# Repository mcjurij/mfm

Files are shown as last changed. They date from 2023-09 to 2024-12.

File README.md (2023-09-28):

# mfm
Mains Frequency Measurement

English: [English version](README_en.md)

Ziel des Projektes ist eine möglichst genaue Messung der Netzfrequenz.

* Dies ist ein reines Spassprojekt,
* ich verdiene mein Geld weder mit Hardwareentwicklung noch mit Embeddedprogrammierung,
* einige meiner Designentscheidungen sind daher u.U. suboptimal. :-)

Mit "Linux PC" ist in meinem Fall ein Fedora (z.Z. Fedora 37) gemeint. Die genutzte Distro spielt aber keine Rolle.

## Über die zwei grundsätzlichen Arten Frequenzen zu messen

1. Man kann ein Gate für eine exakte Zeit (zB genau 1 Sekunde) öffenen und dann zählen wieviele Impulse, erkannt an einer Triggerschwelle, in dieser Zeit erkannt wurden. Dies ist das "klassische" Frequency Counting. Bei hohen Frequenzen funktioniert das ausgezeichnet.

2. Man kann warten bis der Trigger erreicht ist, lässt dann immer wieder neu triggern und bestimmt den Zeitunterschied zwischen den beiden Triggerevents. Um eine hohe Genauigkeit zu erreichen wird dies über eine längere Zeit gemacht, d.h. über mehrer Perioden des Eingangssignals.

Für eine genaue Bestimmung einer Frequenz im Bereich von 50 Hz, also einer sehr niedrigen Frequenz, mit einer Genauigkeit von mindestens +/ 1mHz eher besser, ist Verfahren Nr 2 offensichtlich das einzig geeignete. Bei Verfahren Nr 1 müsste man sehr lange Messen um genug Impulse gesehen zu haben.

Verfahren 2 hat allerdings einen Nachteil. Will man immer die selbe Anzahl an Perioden messen, was hier gemacht wird denn es werden immer 50 Perioden abgemessen, dann ist die MessDAUER abhängig vom MessWERT. Bei einer Frequenz über 50 Hz ist die Messung kürzer als 1 Sekunde. Bei einer Messung unter 50 Hz, länger. Dies zu erwähnen ist wichtig, denn viele mathematische Verfahren gehen von äquidistanten Werten aus. Und auch die Berechnung der Netzzeit benötigt Messwerte im Abstand von 1 Sekunde.

## Über Quarze

Es gibt verschiedene Arten eine Frequenz von zB exakt 10 Mhz zu erzeugen. Standardquarze, temperaturkompensierte Quarze und Quarzöfen (Oven Controlled Crystal Oscillator, OCXO) sind die gängisten Methoden, wobei jeweils eine Balance zwischen Kosten/Aufwand und Anforderung der Anwendung gefunden werden muss. Ein Standardquarz war für meinen Geschmack zu ungenau. Standardquarze sind recht temperaturabhängig. Diese Temperaturabhängigkeit konnte ich in meinen Experimenten deutlich sehen. Eine Genauigkeit von +/- 1 mHz war so nicht zu erreichen, IMO.

Ein temperaturkompensierter Quarz (Temperature Compensated Crystal Oscillator, TCXO) korrigiert den Fehler nach Messung der Temperatur des Quarzes. Das Verfahren ist i.A. sehr viel genauer als ein Standardquarz. Diese sind aber schwer zu bekommen.

Ein Quarzofen hält die Temperatur des Quarzes auf einem konstantem Level. Die Genauigkeit der Frequenz hängt hier im wesentlichem nur noch von der Genauigkeit der Temperaturmessung und des Regelkreises ab. Man bekommt zB den von mir verwendeten Quarzofen für unter 20 Eur auf EBay aus China, inkl. Versand. Und für einen OCXO ist das sehr sehr günstig.  Und ist der Grund warum ich mir die Option TCXO nicht weiter angeschaut habe.

[Beschreibung Hardware](hardware.md)

[Beschreibung Software](software.md)

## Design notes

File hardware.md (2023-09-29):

## Hardware

Das mfm Projekt besteht aus 4 hardware Komponenten. Wovon eine doppelt vorhanden ist.

* Ein GPS disciplined oscillator (GPSDO oder auch GPSDXO) mit 1PPS Ausgang

* Ein oven-controlled crystal oscillator (OCXO) mit 10 Mhz TTL Ausgang (Clock), versorgt über Steckernetzteil.

* Eine "Distributor" genannte Platine zum verdoppeln der 10Mhz Clock und 1PPS Signale, versorgt über Netzanschluss. Schaltplan: Distributor.

* Zwei Platinen mit der Schaltung zur Netzfrequenzmessung. Schaltpläne: Counter ATmega328p v1 & v2. Beide sind fast identisch und haben 3 Eingänge:
  - Netzanschluss, zur Messung und Stromversorgung
  - 10 Mhz TTL Clock für ATmega328
  - 1PPS für ATmega and Pico W

Die zwei Platinen mit der Schaltung zur Netzfrequenzmessung werde ich ab jetzt Counter 1 & 2 nennen. Der Name Counter rührt daher, dass die Hauptaufgabe bei der Frequenzmessung das Zählen zwischen 2 Triggerevents ist. Die übernimmt der ATmega als erste Stufe, hier werden erstmal nur Zeitstempel bestimmt. In der zweiten Stufe wird aus den Zeitstempeln des ATmega vom Pico W eine Frequenz berechnet.

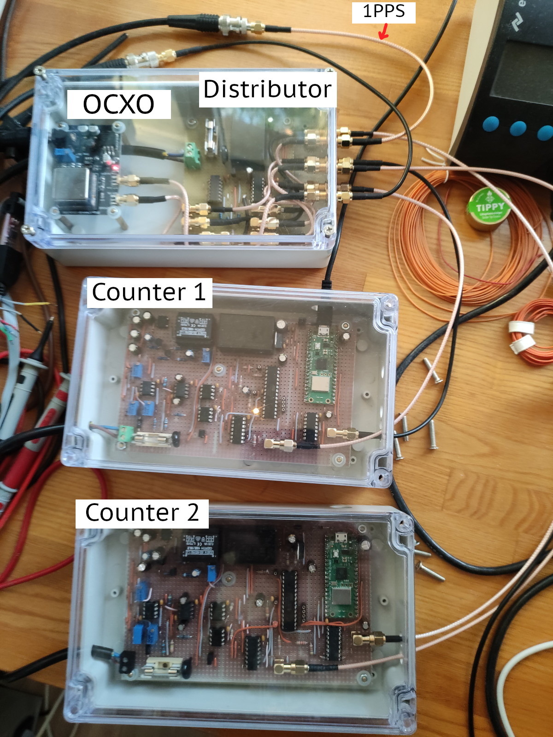
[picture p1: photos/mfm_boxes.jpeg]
3 Boxes


Wer günstig an einen GPSDO mit OCXO kommt, und der 10 MHz als TTL Level ausgibt, ist wohl besser beraten, den zu nehmen statt meiner Lösung. Es funktioniert dann auch nur mit einem Counter und ohne Distributor. Softwareseitig hätte das keine Anpassungen zur Folge (allerdings macht dann das Verschmelzen (merge) von Messwerten, was beim mfm_server beschrieben wird, keinen Sinn mehr, da dies zwei Counter braucht).

### GPSDO

Der Cartain GPSDO ist der billigste, den ich finden konnte. Er funktioniert bisher tadellos. Er gibt einen Impuls pro Sekunde aus (1PPS auch PPS), von c.a. 2,5 Vpp. Bei steigender Flanke ist "atomuhrgenau" jeweils der Beginn einer neuen Sekunde.
Zusätzlich gibt er auch einen 10 Mhz Sinus aus. Da der benutzte Quarz kein OXCO ist, sondern ein spannungsgesteuerter Quarz (VCXO (?)), gibt es ein recht hohes Phasenrauschen.

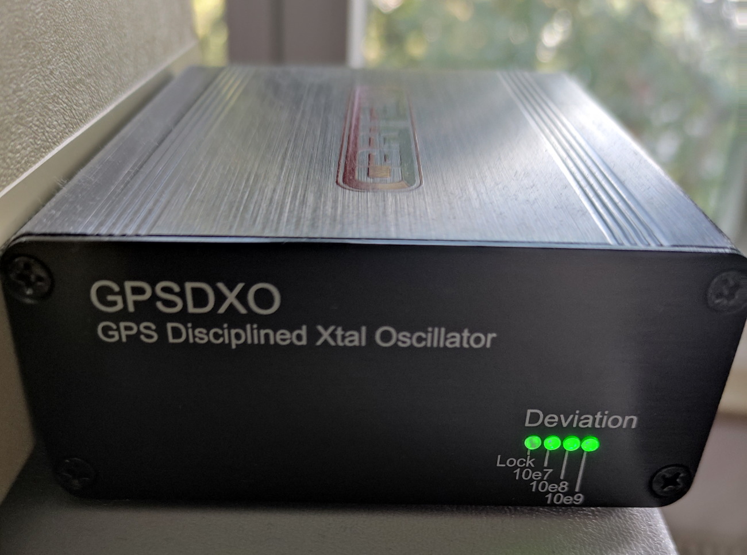
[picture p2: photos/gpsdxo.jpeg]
Cartain GPSDXO


### OCXO & Distributor

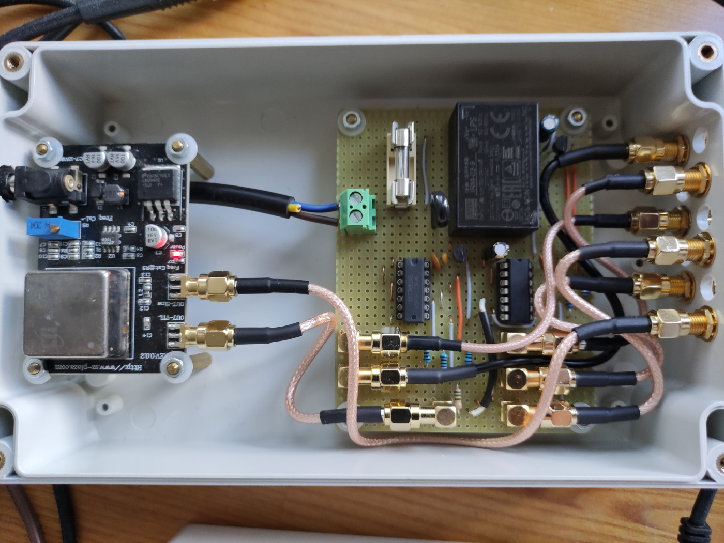
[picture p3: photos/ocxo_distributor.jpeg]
OCXO & Distributor Box


Mit OCXO meine ich die Platine links im Bild.  Der eigentliche Quarzofen, die Metallkiste (siehe Photo), ist von CTI und gebraucht. Nur die Platine ist neu. Es gibt natürlich bessere und genauere Quarzöfen und Beschaltungen aber für diese Anwendung ist die Genauigkeit mehr als ausreichend. Im EEVblog Forum hat wohl der ein oder andere Probleme mit der Einstellung über das Poti, da das Poti am Anschlag ist aber die Frequenz von 10 Mhz nicht genau erreicht wird. Ich hatte das Problem nicht. 

Der Distributor ist rechts im Bild und einfach nur eine Schaltung mit Logikgattern, die die entspr. Signale verdoppeln. Beim 1PPS wird noch die Spannung auf 3,3 V angehoben.
Schematic `hardware/distributor/counter_distributor.kicad_sch`.
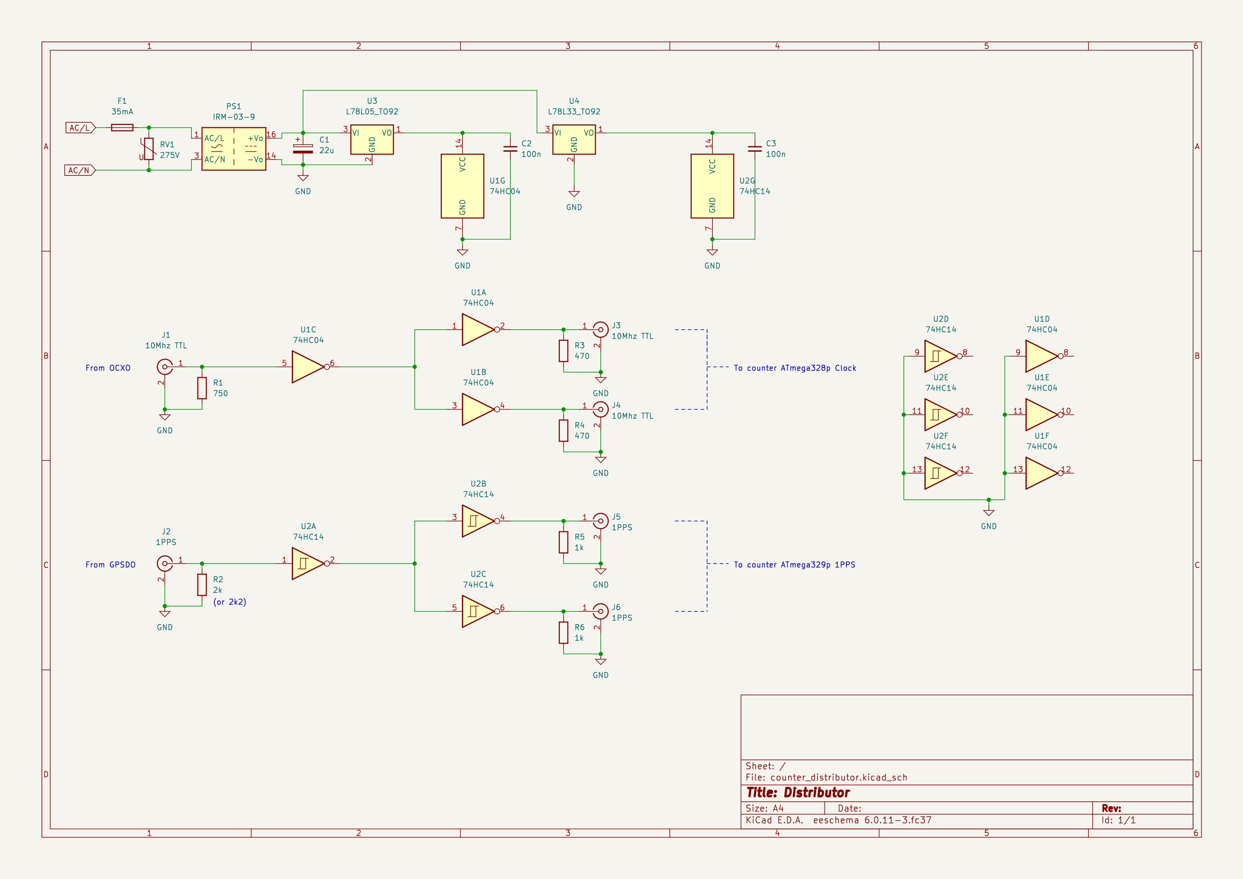
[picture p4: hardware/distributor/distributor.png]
Distributor


Der Distributor hat 2 Ein- und 4 Ausgänge. 10 Mhz TTL auf 2x 10 Mhz TTL als Clock für die ATmegas. 1PPS auf 2x 1PPS.

Der Eingang "From OCXO" ist innerhalb der Box mit dem OCXO "OUT-TTL" Ausgang verbunden. Somit hat die Box einen Eingang für 1PPS und 5 Ausgänge:
2x 10 Mhz TTL out, 2x 1PPS out (3,3 Vpp), 1x Sinus 10 Mhz vom OCXO.

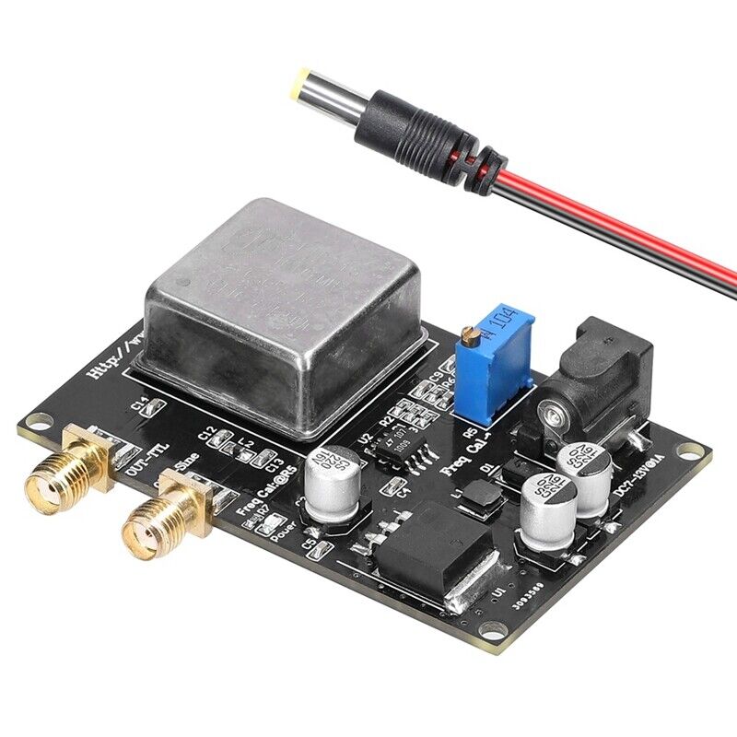
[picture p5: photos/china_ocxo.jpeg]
OCXO


Der OCXO hat neben TTL Ausgang auch einen mit Sinus "OUT-Sine". Dieser wird auch nach aussen geführt damit man mit einem Frequenzmesser aka Frequency Counter nachprüfen kann, ob der OCXO auch genau 10 Mhz ausgibt. Dabei kann der GPSDO 10 Mhz Sinus Out als Referenz benutzt werden.

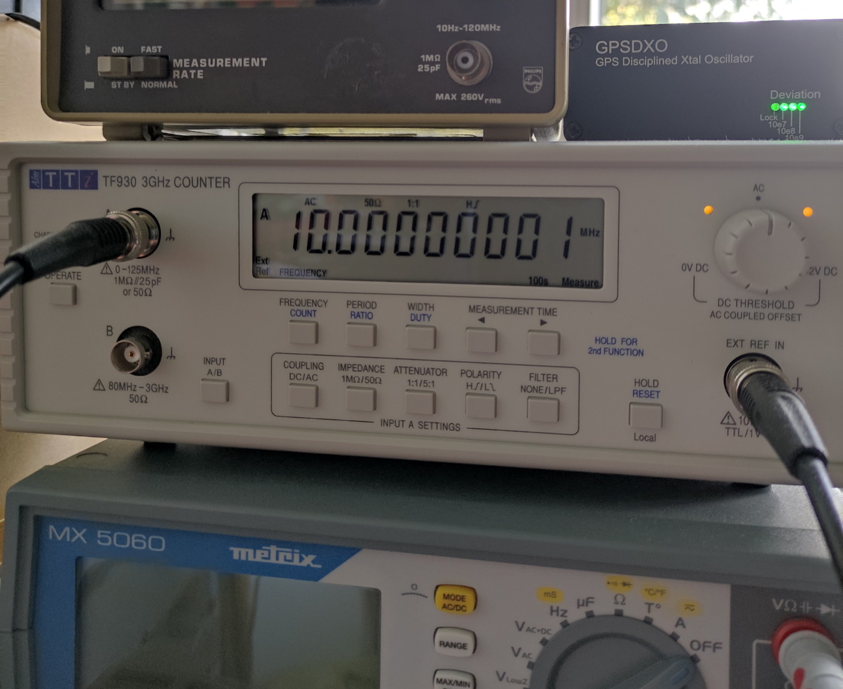
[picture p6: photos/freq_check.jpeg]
Frequenzvergleich OCXO vs GPSDO


### Counter 1 & 2

Die Counter sind bis auf zwei kleine Unterschiede identisch aufgebaut. Beide haben ein Front- und ein Backend. Die Trennung ist dort, wo die Optokoppler sind. Die Masse der +/-5 V Versorgungspannungen ist im Frontend an die Netzspannung gekoppelt. Durch die Optokoppler wird die Netzspannung abgetrennt. Deswegen gibt es zwei Massen GND (Frontend) und GND_2 (Backend) und zwei Spannungsversorgungen.

Die Counter müssen nicht zwingend an 230 V angeschlossen werden. Es geht auch mit einem Steckernetzteil was eine Wechselspannung von c.a. 8 - 10 V liefern sollte. Diese muss an D1 (Suppressordiode, auch TVS Diode) angelegt werden. R1, der Varistor RVAR1 und die Sicherung F1 entfallen dann. Dann braucht man allerdings noch eine Lösung für die symmetrische +/-5V Versorgung des Frontends. Insg. daher die aufwändigere Lösung --allerdings Pflichtprogramm für jeden ohne Trenntrafo. Insb. dann wenn mit einem Oszi auf frontend Seite gemessen werden soll.

Counter 1:
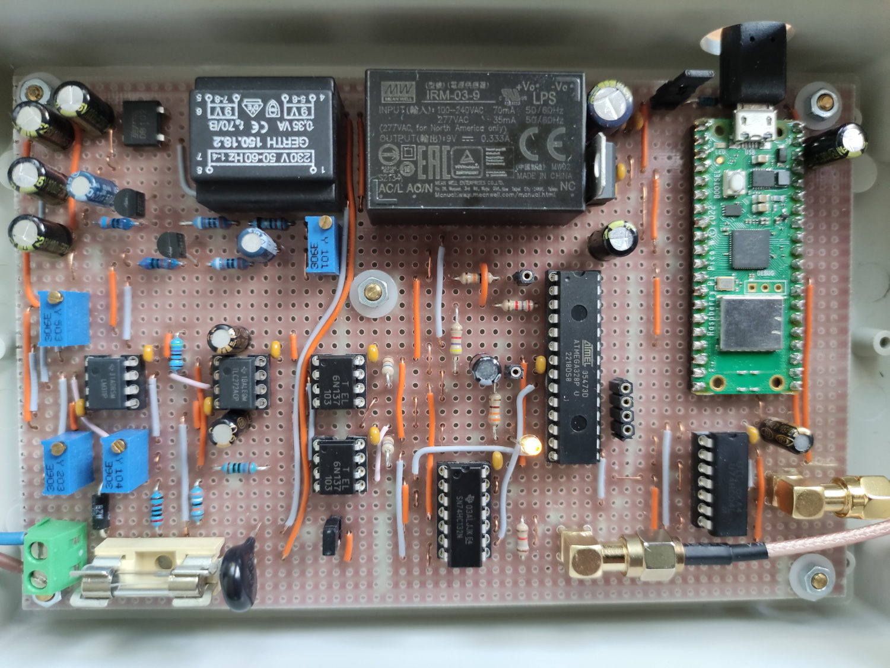
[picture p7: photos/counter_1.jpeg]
Counter 1


Counter 2:
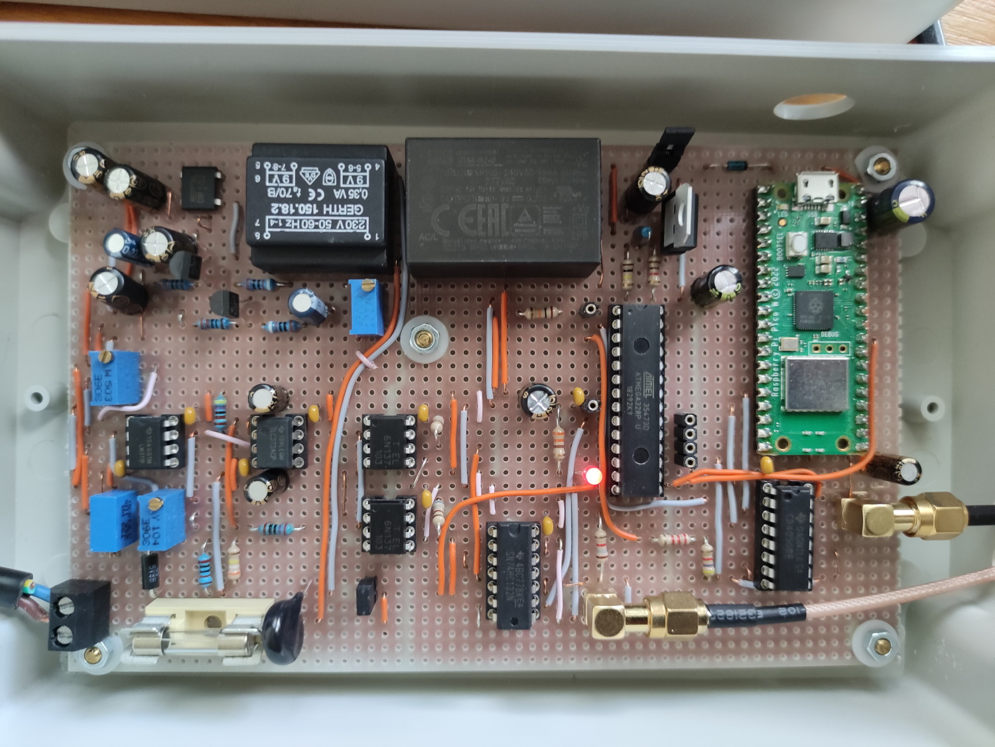
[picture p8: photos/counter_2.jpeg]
Counter 2


Die beiden sind nicht exakt wie in den Schematics aufgebaut. Der Grund für den Längsregler rechts von den IRMs ist, dass die IRM 9V liefern. Das kann man sich aber sparen, wenn man den richtigen IRM nimmt. Also einen mit 5 V am Ausgang.

Der Signalweg anhand Counter 1, Schaltplan `hardware/counter_atmega328p_v2/counter_mcu_2.kicad_sch`.
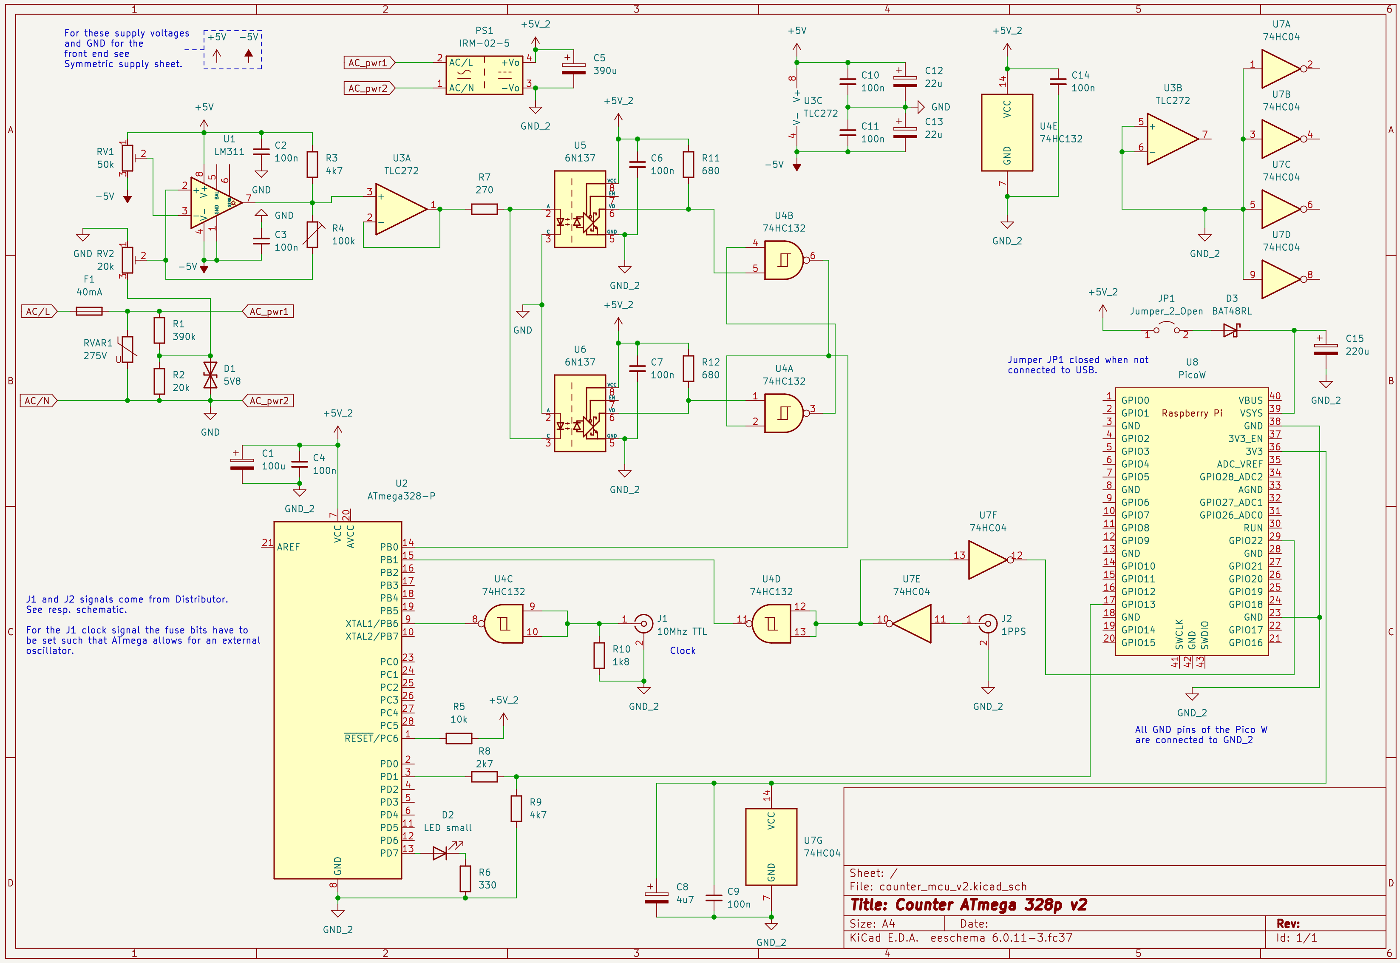
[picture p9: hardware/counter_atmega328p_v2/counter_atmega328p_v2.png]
Counter ATmega328p v2


Frontend:
Über den Spannungsteiler R1,R2 und die Suppressordiode D1 wird die Eingangsspannung auf einen Bruchteil verringert und abgeschnitten. Über RV2 dann weiter verringert und an Komparator U1 gegeben. Dieser vergleicht den Sinus mit einem festem Wert der über RV1 kommt. Das ergibt am Ausgang des Komparators immer einen Wechsel genau dann wenn die Netzspannung über oder unter 0V geht. Dieses Rechtecksignal wird nun durch U3A entkoppelt und an 2 Optokoppler übergeben, die Front- und Backend trennen. 

Backend:
Die Signale aus den 2 Optokopplern werden durch ein S-R Latch U4B, U4A, zu einem Rechtecksingal vereint. Der ATmega hat nur einen Input Capture Eingang (Pin 14). Dieser Eingang wird benutzt um die Zeit zu stoppen in der das Rechteck von 0->1 und von 1->0 geht (im Source wird immer von "rise" und "fall" gesprochen). Die Genauigkeit ergibt sich dabei aus der Clock des ATmegas, die über den Distributor und U4C vom OCXO kommt. Wenn die Netzfrequenz genau 50 Hz beträgt, ist der Abstand zwischen zwei 0->1 Flanken, "rise", oder zwei 1->0 Flanken, "fall", genau 200000 Zyklen, bei einem Takt des ATmega von genau 10 MHz. Macht 200000/(10000000 * s^-1) = 20ms = 1/(50 * s^-1). Die Zeitstempel werden über UART an den Pico W geschickt. Beide MCUs werden über U7E, U7F und U4D mit dem 1PPS Signal versorgt. Warum das so ist beschreibe ich unter Software.

Die LED D2 an Pin 13/PD7 ist an wenn 50 Zeitstempel übertagen wurden und genau so lange aus. Also etwa eine halbe Sekunde an und aus (exakt eine halbe Sekunde an und aus, wenn die Frequenz exakt 50 Hz ist). Es werden 50 0->1 und 50 1->0 Zeitstempel übertagen, 100 in Summe, macht 50 Perioden. Hier kann man nicht erkennen _wann_ eine Messung statt findet. Das liegt nur am Pico W und wann der beginnt Zeitstempel zu verarbeiten ist quasi Zufall. 

Die zwei Unterschiede zwischen Counter 1 (Counter ATmega328p v2) und Counter 2 (Counter ATmega328p v1) sind einmal, dass bei Counter 1 das Signal von RV2 an den _plus_ Pin vom LM311 geht und bei Counter 2 an den _minus_ Pin. Und zum anderem ist der 1PPS Signalweg anders. Die Lösung ist bei Counter ATmega328p v2 IMO besser, was den 1PPS Signalweg angeht. Eine Auswirkung auf die SW hat das nicht. Auf beiden läuft exakt die gleiche SW.

Hinweis: Die Anschlüsse zur Programmierung des ATmegas sind _nicht_ im Schaltplan eingezeichnet.

Hinweis: Das Netzteil für das Frontend ist in einem eigenem Schematic: `hardware/counter_ps/counter_ps.kicad_sch`.
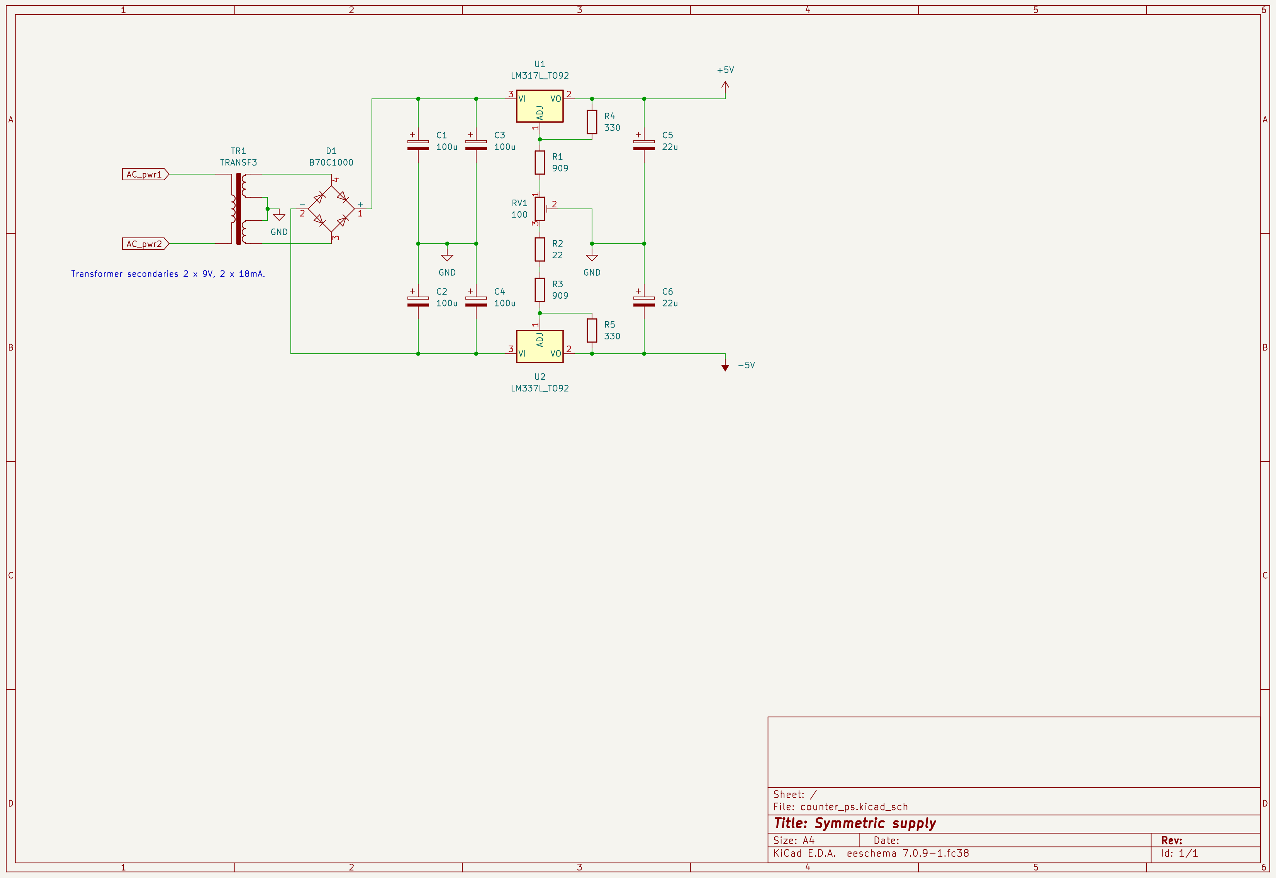
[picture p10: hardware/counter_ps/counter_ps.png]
symmetric power supply Counter PS


Der Grund für 2 Counter ist,
* dass die Messungen beider gegeneinander verglichen werden können.
* Ausfallsicherheit, insb bei SW Updates.
* Beschaltung des LM311 im Frontend unterschiedlich, dadurch etwas anderes Verhalten.

#### Atmel ATmega328p

Der ATmega328p ist ein sehr bekannter Vertreter aus der Atmel AVR Familie. https://www.microchip.com/en-us/product/ATmega328
(Microchip hatte Atmel 2016 gekauft).

Ich benutze ihn hauptsächlich weil ich ihn vorher schon kannte, und er das Input Capture Feature hat (Pin 14 / PB0).  

Der ATmega wird über einen In System Programmer (ISP) programmiert. Mein ISP https://guloshop.de/shop/Mikrocontroller-Programmierung/guloprog-der-Programmer-von-guloshop-de::70.html .
Ausgaben von `dmesg` wenn mein ISP per USB angeschlossen wird:

dmesg Ausgabe ISP dmesg ISP

Damit der ATmega die 10 Mhz Clock an Pin 9 / XTAL1 benutzt, statt der internen, müssen die sog. fuse Bits für einen "external oscillator >8 Mhz" gesetzt werden:
```
avrdude -p atmega328p -P usb -c usbasp -U lfuse:w:0xee:m -U hfuse:w:0xd9:m -U efuse:w:0xff:m
```

Dazu muss das `avrdude` Tool installiert sein, was auch für das Schreiben ins Flash benötigt wird.

Hier ein Bild was den angeschlossenen ISP zeigt. Die Schablone zeigt die Anschlussbelegung.
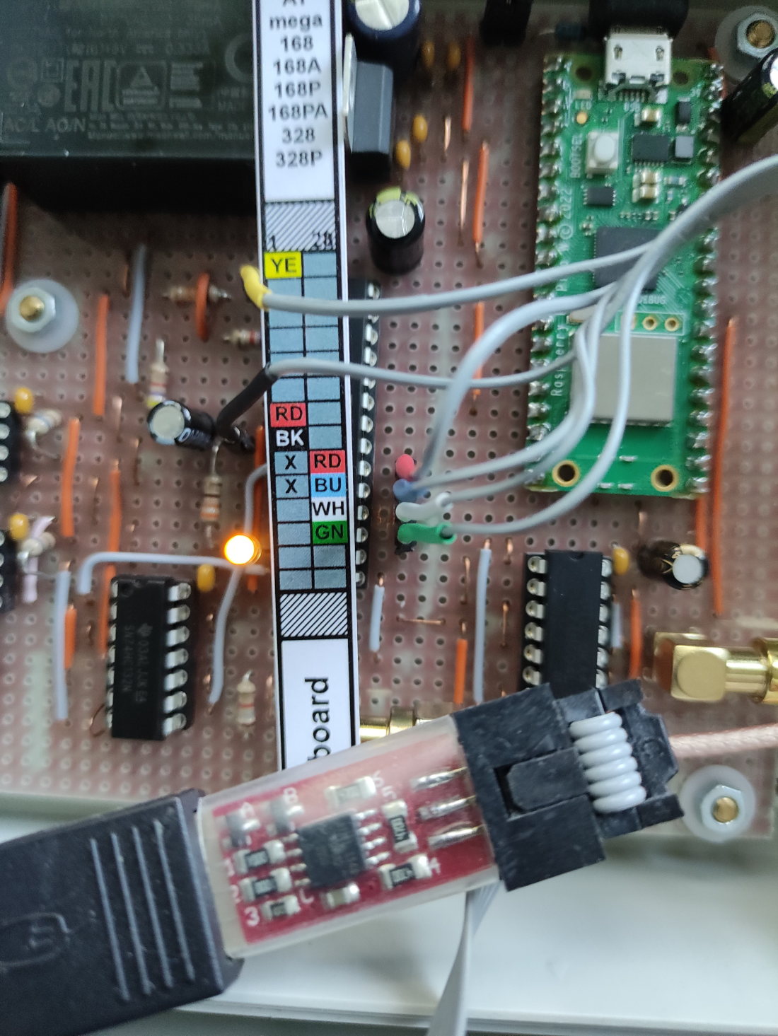
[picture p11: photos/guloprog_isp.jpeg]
guloprog ISP


Dabei sind die Farben vom Hersteller des ISPs vorgegeben und (sehr wahrscheinlich) nicht auf andere ISPs übertragbar.

#### Raspberry Pico W

Der Raspberry Pico W (eigentlich Raspberry Pi Pico W) ist recht neu. Er basiert auf der von Raspberry Pi entwickelten RP2040 MCU, ein dual ARM Cortex M0+ Chip. Takt 133 Mhz.
https://www.raspberrypi.com/documentation/microcontrollers/raspberry-pi-pico.html#raspberry-pi-pico-w

Ich benutze ihn hauptsächlich weil er Wlan, eine gut dokumentierte API und einen geringen Preis hat.

Zwar ist die Spannungsversorung auf 5V ausgelegt, sie wird aber vom Pico W auf 3,3V umgewandelt. Alle I/O Pins dürfen somit nur mit max. 3,3V betrieben werden. 3,3V für eigene Bauteile können beim Pico W abgegriffen werden (Pin 36/ 3V3). Das ist nützlich für das level shifting 3,3 V <-> 5 V.

Das Wlan ist, zumindest bei mir auf der Streifenrasterplatine (Epoxyd), sehr schwach. Ich habe daher einen eigenen Wlan Access Point in direkter Nähe, der ausschliesslich für die Pico Ws ist. Selbst damit reagiert das Ganze immer noch sehr auf Störungen.

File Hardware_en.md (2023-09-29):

## Hardware

The mfm project consists of 4 hardware components. One of which is present twice.

* A GPS disciplined oscillator (GPSDO or GPSDXO) with 1PPS output

* An oven-controlled crystal oscillator (OCXO) with 10 MHz TTL output (clock), powered by a plug-in power supply.

* A board called a "Distributor" for doubling the 10Mhz clock and 1PPS signals, powered via mains connection.

* Two circuit boards with the circuit for measuring the mains frequency. Circuit diagrams: Counter ATmega328p v1 & v2. Both are almost identical and have 3 inputs:
  - Mains connection, for measurement and power supply
  - 10 MHz TTL clock for the ATmega328
  - 1PPS for the ATmega and the Pico W

From now on I will call the two boards with the circuit for the mains frequency measurement Counters 1 & 2. The name Counter comes from the fact that the main task in frequency measurement is counting between two trigger events. The ATmega is at the first stage and sends a time stamp on every trigger. In the second stage the Pico W computes the frequency from the time stamps coming from the ATmega.

3 Boxes

If you can get a GPSDO with OCXO cheaply and that outputs 10 MHz at TTL level, you would probably be better off taking that instead of my solution. It is also possible to use a single Counter and no Distributor. On the software side, this would not result in any adjustments (however, merging measured values, which is described for the mfm_server, no longer makes sense, as this requires two counters).

### GPSDO

The Cartain GPSDO is the cheapest I could find. It's working perfectly so far. It emits a one pulse per second (1PPS also PPS) signal, of approx. 2.5 Vpp. Every rising edge marks the beginning of a new second "accurate to an atomic clock".
In addition, it also outputs a 10 MHz sine wave. Since the crystal used is not an OXCO, but a voltage-controlled crystal (VCXO (?)), there is quite a bit of phase noise.

Cartain GPSDXO

### OCXO & Distributor

OCXO & Distributor box

By OCXO I mean the board on the left in the photo. The actual crystal oven, the metal box (see photo), is from CTI and used. Only the circuit board is new. There are of course better and more precise crystal ovens and circuits, but the accuracy is more than sufficient for this application. In the EEVblog forum, some people mentioned to have problems with the potentiometer setting, since the potentiometer was at the limit but a frequency of 10 MHz not exactly reached. I didn't have that problem.

The distributor is on the right in the photo and is simply a circuit with logic gates that double the corresponding signals. The 1PPS signal gets its voltage increased to 3.3 V.

Schematic `hardware/distributor/counter_distributor.kicad_sch`.
Distributor

The distributor has 2 inputs and 4 outputs. 10 Mhz TTL to 2x 10 Mhz TTL as clock for the ATmegas. 1PPS to 2x 1PPS.

The "From OCXO" input is connected to the OCXO "OUT-TTL" output inside the box. The box therefore has an input for 1PPS and 5 outputs:
2x 10 MHz TTL out, 2x 1PPS out (3.3 Vpp), 1x sine 10 MHz from the OCXO.

OCXO

In addition to the TTL output, the OCXO also has an “OUT-Sine” sine output. This is also led outside so that you can use a frequency counter to check whether the OCXO is exactly at 10 MHz. The GPSDO 10 Mhz sine output can be used as a reference.

compare OCXO vs GPSDO

### Counter 1 & 2

The Counters are identical except for two small differences. Both have a front and a back end. The separation is where the opto-isolators are. The ground of the +/-5 V supply voltages is coupled to the mains voltage in the front end. The mains voltage is separated by the opto-isolators. That's why there are two grounds GND (front end) and GND_2 (back end) and two power supplies.

The Counters do not necessarily have to be connected to 230 V. It is also possible with a plug-in power supply, which outputs an AC voltage of approx. 8 - 10 V. This must be connected to D1 (suppressor diode, also TVS diode). R1, the varistor RVAR1 and the fuse F1 are then omitted. But then you need a solution for the symmetrical +/-5V supply for the front end. More effort --although mandatory for everyone without an isolating transformer. Especially if you want to measure with a scope on the front end side.

Counter 1:
Counter 1

Counter 2:
Counter 2

The two are not built exactly as in the schematics. The reason for the linear regulator to the right of the IRMs is because the IRMs output is 9V. If you take the right IRM, those with a 5 V output, this isn't needed.

The signal path using Counter 1, schematic `hardware/counter_atmega328p_v2/counter_mcu_2.kicad_sch`.
Counter ATmega328p v2

Front end:
The input voltage is reduced to a fraction and clipped by the voltage divider R1, R2 and the suppressor diode D1. Then further reduced via RV2 and sent to the comparator U1, a LM311. It compares the sine with a fixed value that comes via RV1. This always results in a change at the output of the comparator exactly when the mains voltage goes above or below 0V. This square wave signal is now decoupled by U3A and passed to 2 opto-isolators that separate the front from the back end.

Back end:
The signals from the 2 opto-isolators are combined into a single square wave signal by the S-R latch U4B, U4A. The ATmega only has one input capture input (pin 14). This input is used to stop the time in which the signal goes from 0->1 and from 1->0 (the source code always speaks of "rise" and "fall"). The accuracy results from the clock of the ATmega, which comes from the OCXO via the Distributor and U4C. If the mains frequency is exactly 50 Hz, the distance between two 0->1 edges, "rise", or two 1->0 edges, "fall", is exactly 200,000 cycles, with the clock of the ATmega at exactly 10 MHz. Results in 200000/(10000000 * s^-1) = 20ms = 1/(50 * s^-1) period time. The timestamps are sent to the Pico W via UART. Both MCUs are supplied with the 1PPS signal via U7E, U7F and U4D. I will describe why this has been done so in the software description.

The LED D2 on pin 13/PD7 is on when 50 time stamps have been transferred and off for exactly that long. So about half a second on and off (exactly half a second on and off if the frequency is exactly 50 Hz). 50 0->1 plus 50 1->0 timestamps are transmitted, 100 in total, making 50 periods. It doesn't tell you _when_ a measurement is taking place. This is only due to the Pico W and when it starts processing timestamps is essentially a coincidence.

The two differences between Counter 1 (Counter ATmega328p v2) and Counter 2 (Counter ATmega328p v1) are that with Counter 1 the signal from RV2 goes to the _plus_ pin of the LM311 and with Counter 2 to the _minus_ pin. And secondly, the 1PPS signal path is different. The solution is better with Counter ATmega328p v2 IMO as far as the 1PPS signal path is concerned. This has no effect on the SW. The exact same software runs on both.

Note: The connections for ISP programming the ATmega are _not_ shown in the schematic.

Note: The power supply for the front end is in its own schematic: `hardware/counter_ps/counter_ps.kicad_sch`.
symmetric power supply Counter PS

The reason for 2 counters is,
* that the measurements of both can be compared against each other.
* Reliability, especially when doing SW updates.
* Wiring of the LM311 in the front end is different, resulting in slightly different behavior.

#### Atmel ATmega328p

The ATmega328p is a very well-known representative from the Atmel AVR family. https://www.microchip.com/en-us/product/ATmega328
(Microchip bought Atmel in 2016).

I use it mainly because I knew it before and it has the input capture feature (pin 14 / PB0).

The ATmega is programmed using an In System Programmer (ISP). My ISP is https://guloshop.de/shop/Microcontroller-Programmierung/guloprog-der-Programmer-von-guloshop-de::70.html .
Outputs from `dmesg` when my ISP is connected via USB:
dmesg output ISP dmesg ISP

In order for the ATmega to use the 10 Mhz clock on pin 9 / XTAL1 instead of the internal one, the so-called fuse bits must be set for an "external oscillator >8 Mhz":
```
avrdude -p atmega328p -P usb -c usbasp -U lfuse:w:0xee:m -U hfuse:w:0xd9:m -U efuse:w:0xff:m
```

To do this, the `avrdude` tool must be installed, which is also required for writing to flash.

Here is a photo showing the connected ISP. The template shows the pin assignment.
guloprog ISP

The colors are specified by the ISP manufacturer and (very likely) cannot be transferred to other ISPs.

#### Raspberry Pico W

The Raspberry Pico W (actually Raspberry Pi Pico W) is quite new. It is based on the RP2040 MCU developed by Raspberry Pi, a dual ARM Cortex M0+ chip. Clocked at 133 MHz.
https://www.raspberrypi.com/documentation/microcontrollers/raspberry-pi-pico.html#raspberry-pi-pico-w

I use it mainly because it has WiFi, a well-documented API, and a low price.

Although the voltage supply is designed for 5V, the Pico W converts it to 3.3V. All I/O pins may therefore only be operated with a maximum of 3.3V. 3.3V for your own components can be tapped from the Pico W (pin 36/3V3). This is useful for level shifting 3.3 V <-> 5 V.

The WiFi is very weak, at least for me on the strip grid board (epoxy). I therefore have a dedicated WiFi access point in the immediate vicinity, which is exclusively for the two Pico Ws. Even with that, the whole thing is still very responsive to EMI noise.

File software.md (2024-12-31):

## Software

Die Software besteht aus 4 Komponenten. Eine Embedded SW für jeweils ATmega und Pico W. Einem Server, der die Daten die per WLan reinkommen, entgegennimmt. Und einem einfachen Tool zur graphischen Ausgabe der Daten.

### Embedded

Um die krosskompilierte SW auf die MCUs zu übertragen werden 2 völlig verschiedene Methoden benutzt. Der ATmega wird über einen In System Programmer (ISP) programmiert. Der Pico W hat einen Taster. Wird der beim Einschalten des Pico Ws gehalten, so geht der Pico W in eine spezielle Boot-Sequenz (die nicht überschrieben werden kann). Damit kann man über USB einen "Massenspeicher" mounten und eine .uf2 Datei dort hinkopieren. Das erkennt der Pico W und überträgt diese dann in sein Flashspeicher.

Ich kann mir vorstellen, dass der Pico W zur Programmierung des Atmegas benutzt werden kann. Das habe ich aus Zeitmangel nicht verfolgt. Es hätte den Vorteil, dass man keinen extra ISP braucht. Allerdings braucht man wegen der 3,3V I/O Spannung des Picos einen Treiber (auch level shifter oder logic converter genannt) zur Umsetzung und da sehe ich Platzprobleme. Die man allerdings vermutlich nicht hätte, wenn man einen kleineren Vertreter der ATmel Serie nehmen würde (ATtiny).  Der ATmega328p ist für diese Anwendung klar überdimensioniert. Zwar laufen ATmega/ATtiny auch mit 3,3V, ich weiss aber nicht ob das für 10Mhz reicht. Und an den Eingängen des ATmega/ATtiny dürfte dann nicht mehr als 3,3 + 0,5 V angelegt werden. 

#### Atmel ATmega328p

Der Source für den ATmega ist hier:
ATmega 328 src

Es gibt nur eine Datei: `main.c`. Da der ATmega nur die Zeitstempel zwischen den Flanken des Rechtecksignals bestimmt und diese per UART an den Pico W schickt, passiert hier nicht viel. Das 1PPS Signal wird benutzt um den Zähler für die Zeitstempel auf 0 zu setzen.

Damit das Makefile durchläuft muss die avr-gcc Toolchain und zum flashen der avrdude installiert sein. Wenn der ISP zu dem im Makefile passt und angeschlossen ist, kann mit `make program` in einem Schritt kompiliert und geflashed werden.

#### Raspberry Pico W

Der Source für den Pico W ist hier:
Pico W src

Ich benutze kein OS. Der Programmierer legt fest, was auf den 2 Kernen des Pico Ws, Core0 und Core1, laufen soll. Ich habe es so aufgeteilt, dass die Annahme (über UART) und Verarbeitung der Zeitstempel, die vom ATmega kommen, auf Core1 passiert. Die Kommunikation mit dem Server auf Core0 (dort wird main() gestartet).

Der Wlan Chip benutzt Interrupts, die mit Core0 verdrahtet sind und daher kann der Wlan Code nur auf Core0 laufen.

Um eine genaue Zeit zur ermitteln, holt sich der Pico W beim Start die Zeit von mfm_server. Dieser gibt die Zeit des Hostrechners zurück, die ungenau ist, was kein Problem ist solange sie genau genug ist um die richtige Sekunde zu bestimmen (der Hostrechner bekommt seine Zeit wiederum i.d.R. über NTP. Das Verfahren ist abhängig von der Netzwerklatenz). Diese wird nun mit dem 1PPS Signal abgeglichen und damit erhält man eine sehr genaue Zeit. 
Ich benutze nicht die Uhr (RTC) des Picos. Der Standardquarz des Picos macht eine ständige Korrektur der Zeit nötig, egal wie man es macht.  Der Pico hat einen Zähler der ab Start hochzählt. Zu diesem addiere ich die Mikrosekunden seit 1.1.1970 0 Uhr.  In einer Interruptroutine, die an das 1PPS Signal gekoppelt ist, wird jede Sekunde geschaut um wieviele Mikrosekunden der Zähler (+ Mikrosekunden seit 1.1.1970 0 Uhr) korrigiert werden muss.
Da die Zeitstempel des ATmegas ebenfalls mit dem 1PPS Signal synchronisiert sind, kann die Messzeit (zumindest in der Theorie) sehr genau bestimmt werden. Sobald eine Messung stattgefunden hat kommt vom Pico nur die Information in welcher Sekunde die Messung war und vom ATmega die Mikrosekunde (Start/Ende der Messung). Der Zeitpunkt der Messung liegt in der Mitte zwischen Start und Ende der Messung. Dabei ist es wichtig zu beachten, dass der Start oder das Ende der Messung nicht auf einer Sekundengrenze liegen müssen und dass eine Messung länger (oder kürzer) als eine Sekunde sein kann.

- `conf.h` - Konfiguration wie MAINS_FREQ
- `freq.c` - Empfängt Zeitstempel vom ATmega und berechnet daraus Frequenz. Läuft auf Core1.
- `main.c` - enthält main() was auf Core0 startet, startet Core1. Empfängt auf Core0 die Daten die von `freq.c` in den `ringbuffer.c` geschrieben wurden und sendet sie an den mfm_server.
- `ntime.c` - Bestimmung der genauen Zeit aus Kombination mit Zeit vom Linux PC und 1PPS.
- `proto.c` - Protokoll-definition.
- `tcp_client.c` - Kommunikation mit dem mfm_server. Die lwip call-back API ist _sehr_ fummelig.
- `ringbuffer.c` - Speichern von Messwerten wenn Netzwerkverbindung (kurz) nicht verfügbar.

Zunächst mal das C SDK einrichten. https://www.raspberrypi.com/documentation/microcontrollers/c_sdk.html#sdk-setup
Unter https://www.raspberrypi.com/documentation/microcontrollers/c_sdk.html#quick-start-your-own-project steht welche Linux Packages installiert werden müssen.

Git clone und Umgebungsvariable setzen.
```
git clone https://github.com/raspberrypi/pico-sdk.git

cd pico-sdk
git submodule update --init

export PICO_SDK_PATH=$HOME/<path to pico sdk>/pico-sdk/
```

Jetzt zum embedded/Pico_W/mfm Verzeichnis um die IP zu setzen von dem Rechner auf dem der mfm_server läuft.
```
cd embedded/Pico_W/mfm
```

Dazu diese Zeile in embedded/Pico_W/mfm/CMakeLists.txt ändern.
``` 
 TCP_SERVER_IP=\"192.168.178.XXX\"
```

In das Pico W Verzeichnis wechseln (embedded/Pico_W), dann cmake Aufruf.

```
cd ..

mkdir build
cd build

cmake -DPICO_BOARD=pico_w -DWIFI_SSID="<your SSID>" -DWIFI_PASSWORD="<your password>" ..
```

Das sollte zu diesen Ausgaben führen. Ich habe meine Pfade hier geschwärzt.
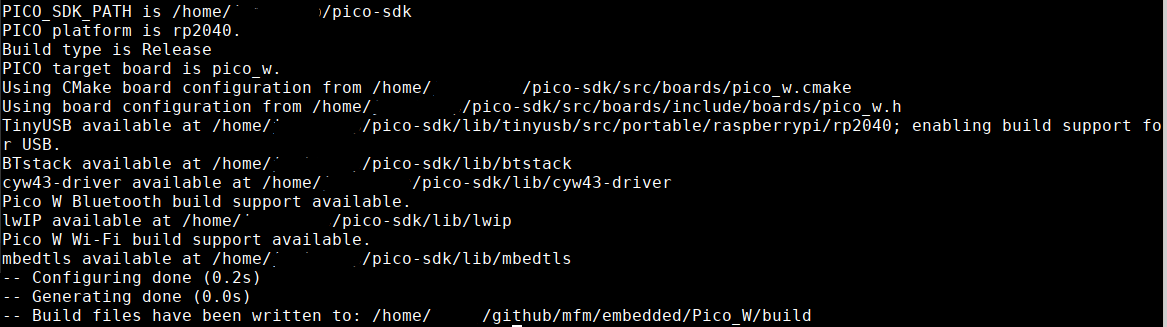
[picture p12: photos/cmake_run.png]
cmake Ausgabe cmake


Zum Bauen `make -j9`. Die UF2 Datei zum flashen ist unter `embedded/Pico_W/build/mfm/mfm_pico_w.uf2`  (747 kb).

Beim nächsten Mal Bauen einfach
```
cd build
make -j9
```
und den cmake Aufruf weglassen.

### Auf Linux PC

Auf einem Linux PC läuft der mfm_server, der die Daten die über Wlan von den Pico Ws kommen annimmt, weiterverarbeitet und in Dateien schreibt. Diese können von einer GUI, dem "Binge Watcher" bzw mfm_bwatcher, gelesen werden. 

Die Ausgaben, die mit printf() gemacht werden, werden über USB übertragen. Dazu auf dem Linux PC `minicom -C minicom.log -b 115200 -o -D /dev/ttyACM0` eingeben, nachdem der Pico W gestartet wurde. Die Übertragung der Ausgaben über USB hängt sich bei mir manchmal auf (nach mehreren Stunden oder Tagen). Der Pico W läuft dann aber noch.

Nach dem Start des Pico Ws wird erst versucht sich mit dem Wlan zu verbinden (die SSID und das Passwort wird wie grade gezeigt beim cmake Aufruf mit übergeben), gelingt das wird eine Zeitsynchronisation mit dem Linux PC durchgeführt. Danach werden die Zeitstempel vom ATmega gelesen. Wenn nichts "ungewöhnliches" passiert wird etwa alle 4 Sekunden

```
Interrupt handler count msg: XXX
```
ausgegeben. Wobei XXX die Anzahl der bereits verarbeiteten Zeitstempel ist.

#### mfm_server

Der mfm_server sollte mit einem `make` direkt bauen.
Der Server startet pro Verbindung, also pro Counter, einen Thread. Die zwei Threads übergeben dann die Messwerte an einen Thread, der die Daten pro Counter rausschreibt und zusätzlich kombiniert. 

Der mfm_server ist (noch) kein richtiger Server, es fehlt das sog daemonizing, dazu gehört das Entkoppeln vom Terminal. Z.Z. gibt es auch keine Möglichkeit den Server mit einem Kontrollprogramm sauber runterzufahren.

- `conn_slots.c` - jeder Pico W bekommt einen eigenen connection slot, nutzt die Pico ID um zu erkennen, dass der selbe Pico W sich erneut angemeldet hat.
- `file_mgr.c` - File Management und Rotation.
- `process_data.c` - Datenauswertung.
- `proto.c` - Protokoll-definition, exakte Kopie der Datei im embedded/Pico_W/mfm Verzeichnis.
- `server.c`- Enhält main(), nimmt Netzwerkverbingen an und startet pro Pico W einen Thread.

Die Picos haben eine eindeutige ID, diese kann mit https://github.com/mcjurij/mfm/blob/85a41c4bb33529b7771d14aba3f1979061e204ab/embedded/Pico_W/mfm/main.c#L51 abgefragt werden. Im mfm_server dient sie insb. dazu die Dateinamen für die Counter-bezogenen Dateien zu bestimmen. Nachdem ein Pico W eine Verbindung zum mfm_server aufgebaut hat sendet er als erstes seine ID.

Damit die Pico Ws Kontakt zum mfm_server aufnehmen können, ist es evtl. erforderlich den Port 4200 in einer Firewall freizugeben, abhängig von der Linux Distro. Auf meinem Fedora dazu
```
firewall-cmd --permanent --add-port=4200/tcp

firewall-cmd --reload
```
als root User benutzen.

##### Ausgabedaten

Neben dem mfm_server eigenem Logfile `log.txt` werden diverse Dateien geschrieben, an die laufend angehängt wird. Kommt eine Datei von einem bestimmten Counter enthält der Dateiname die Pico ID. In jedem Fall das aktuelle Datum. An einem Beispieltag, ich nehme den 2023-09-25, wird das schnell klar. In der ersten Spalte in allen Dateien ist immer eine Zeit, entweder in us-Epoch oder Epoch. Mit us-Epoch sind die Mikrosekunden seit dem 1.1.1970 0 Uhr gemeint (eine 16-stellige Zahl). Mit Epoch die Sekunden seit dem 1.1.1970 0 Uhr. Meine Pico Ws haben die IDs Counter 1: E661A4D41723262A, Counter 2: E661A4D41770802F.

| Dateiname | Inhalt |
| --- | --- |
|`meas_data_E661A4D41723262A_2023-09-25.txt`|Messwerte von Counter 1 mit us-Epoch Zeit|
|`meas_data_E661A4D41770802F_2023-09-25.txt`|Messwerte von Counter 2 mit us-Epoch Zeit|
|`meas_data_local_E661A4D41723262A_2023-09-25.txt`|Messwerte von Counter 1 mit lokaler Zeit|
|`meas_data_local_E661A4D41770802F_2023-09-25.txt`|Messwerte von Counter 2 mit lokaler Zeit|
|`meas_sgfit_E661A4D41723262A_2023-09-25.txt`|Messwerte von Counter 1 mit us-Epoch Zeit, mit Interpolation & Savitzky-Golay Filter|
|`meas_sgfit_E661A4D41770802F_2023-09-25.txt`|Messwerte von Counter 2 mit us-Epoch Zeit, mit Interpolation & Savitzky-Golay Filter|
|`meas_sgfit_local_E661A4D41723262A_2023-09-25.txt`|Messwerte von Counter 1 mit lokaler Zeit, mit Interpolation & Savitzky-Golay Filter|
|`meas_sgfit_local_E661A4D41770802F_2023-09-25.txt`|Messwerte von Counter 1 mit lokaler Zeit, mit Interpolation & Savitzky-Golay Filter|
|`meas_merge_2023-09-25.txt`|Verschmolzene Messwerte von Counter 1 & 2 mit us-Epoch Zeit, mit Interpolation|
|`meas_merge_sgfit_2023-09-25.txt`|Verschmolzene Messwerte von Counter 1 & 2 mit us-Epoch Zeit, mit Interpolation & Savitzky-Golay Filter|
|`gridtime_2023-09-25.txt`|Netzzeit mit Epoch Zeit|
|`gridtime_local_2023-09-25.txt`|Netzzeit mit lokaler Zeit|
|`incidents_E661A4D41723262A_2023-09-25.txt`|Incidents von Counter 1|
|`incidents_E661A4D41770802F_2023-09-25.txt`|Incidents von Counter 2|

Die Interpolation ist einfach zwischen zwei Messwerten linear interpoliert, und zwar so, dass man einen Wert pro Sekunde erhält. Der Savitzky-Golay Filter kann (in dieser Form) nur mit äquidistanten Werten arbeiten. Bei `meas_merge_*` wird der Mittelwert aus den beiden Interpolationen von Counter 1 und 2 genommen. Bei `meas_merge_sgfit_*` wird für Counter 1 & 2 jeweils erst interpoliert, dann jeweils der Savitzky-Golay Filter angewendet und danach der Mittelwert von diesen beiden Werten genommen.

Die Netzzeit wird aus den Messwerten berechnet die in `meas_merge_sgfit_*` geschrieben werden. In `gridtime_2023-09-25.txt` steht die Epoch Zeit in der ersten Spalte. Das sind die Sekunden seit dem 1.1.1970 0 Uhr. In der zweiten Spalte steht der Netzzeitoffset.

Welchen Effekt der Savitzky-Golay Filter auf die Messwerte hat, kann man sehr schön im mfm_bwatcher sehen, in dem man sich zB. `meas_data_E661A4D41723262A_2023-09-25.txt` _und_ `meas_sgfit_E661A4D41723262A_2023-09-25.txt` anschaut, wobei man natürlich die Pico W ID und das Datum anpassen muss. Implementation siehe 
https://github.com/mcjurij/mfm/blob/0261355ed0bb614fb97571ce3041f7e02aebb63d/mfm_server/process_data.c#L542

Im mfm_server Log-File `log.txt` finden sich verschiedene Dinge: Meldungen zum Zeitabgleich, Meldungen zur File Rotation, Meldungen zu unplausibel langen Abständen zwischen 2 Messungen, Meldungen zu empfangenen Incidents die vom Pico W generiert werden.

Zu Incidents schreibe ich weiter unten was.

##### Starten mit Netzzeit

Beim Start des mfm_server kann die "offizielle" Netzzeit von zB https://www.swissgrid.ch/de/home/operation/grid-data/current-data.html#wide-area-monitoring (nach unten scrollen) als Kommandozeilenargument übergeben werden.
Der Wert von "Aktuelle Netzzeitabweichung:" ist die Differenz zwischen Netzzeit minus aktueller Uhrzeit.

Z.B. startet
```
./mfm_server 15.23
```
den mfm_server so, dass statt 0 15,23 Sekunden als Netzzeitoffset zum Zeitpunkt des Starts genommen wird. Das ist nicht perfekt genau, da zwischen dem Start des Programms und dem Start der eigenen Netzzeitberechnung eine Pause ist, aber ausreichend.

#### mfm_bwatcher

Ein einfaches Tool zur graphischen Ausgabe der Daten, ähnlich einem Funktionsplotter, aber mit ein paar speziellen Features für diese Anwendung. Es muss Qt 6 installiert sein. Aktuell benutze ich Qt 6.4.3 mit Qt Creator.
Zum Konfigurieren des Projekts auf File->Open File or Project gehen, dann `mfm_bwatcher.pro` laden, dann bei "Configure Project" nur "Desktop ..." auswählen, und auf "Configure Project" Button klicken. Dann unten links auf das grüne Dreieck "Run" clicken. Damit wird gebaut und die mfm_bwatcher GUI gestartet.

Der mfm_bwatcher versteht nur die Dateien die eine us-Epoch Zeit haben (wie zB `meas_data_E661A4D41770802F_2023-09-25.txt`), nicht die mit lokaler Zeit (wie zB `meas_data_local_E661A4D41770802F_2023-09-25.txt`). Die mit lokaler Zeit sind für andere Plotter wie zB gnuplot gedacht. Die Datei für die Netzzeit (zB `gridtime_2023-09-25.txt` siehe oben), darf nur die Epoch in der ersten Spalte haben.

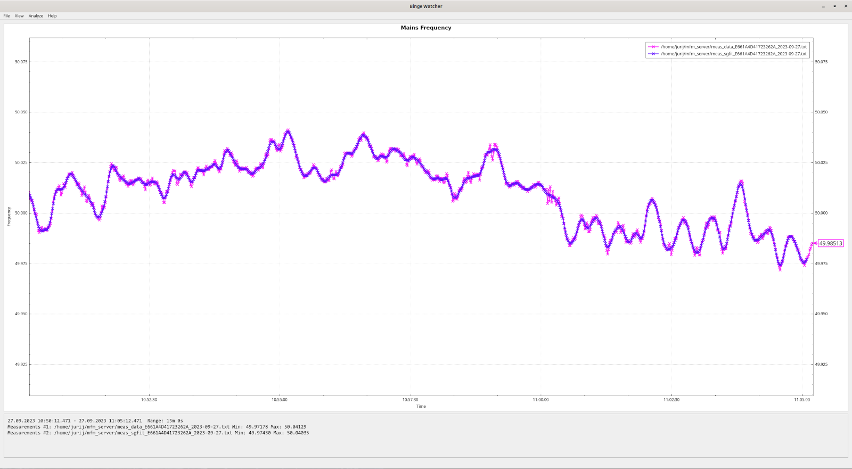
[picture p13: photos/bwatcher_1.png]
Binge Watcher Follow Mode

Dieser Screenshot zeigt die Daten von Counter 1: `meas_data_E661A4D41723262A_2023-09-27.txt` und `meas_sgfit_E661A4D41723262A_2023-09-27.txt`. Man sieht den Effekt des Savitzky-Golay Filters.
Im "Follow mode" werden die Dateien vom mfm_server immer am Ende neu gelesen und der Graph im Sekundentakt erneuert. Zu erkennen ist der Follow mode an dem Kästchen mit Wert und Pfeil an der rechten y-Achse (im Source AxisTag genannt).

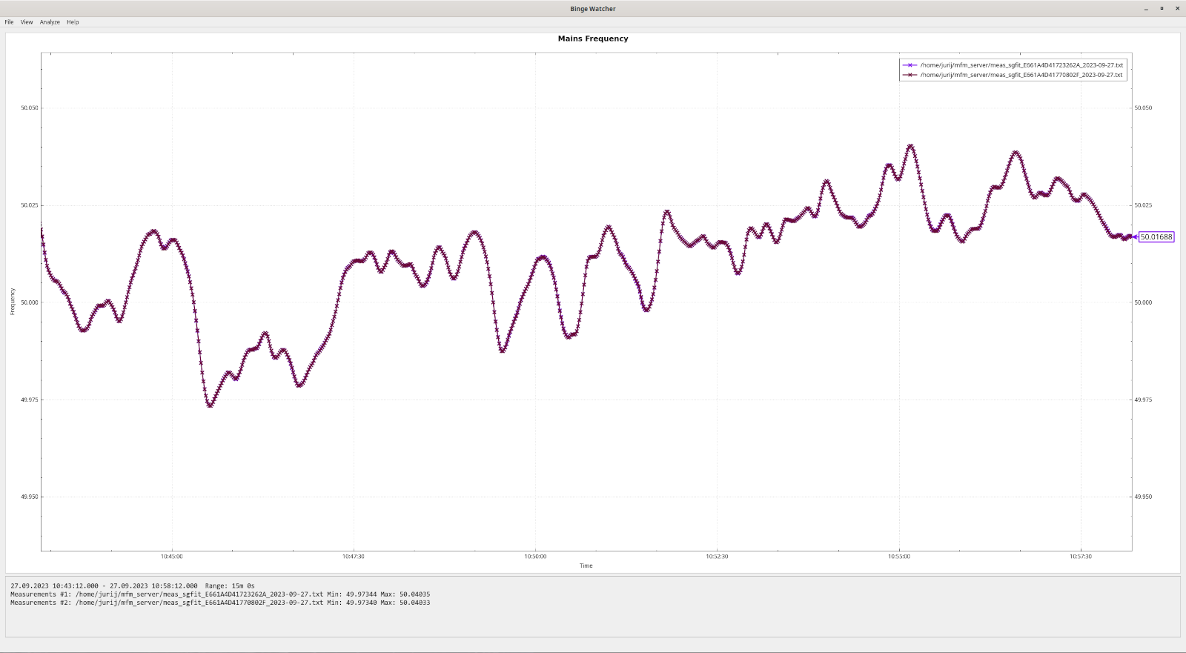
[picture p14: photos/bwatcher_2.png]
Binge Watcher Follow Mode

Dieser Screenshot zeigt die Daten von Counter 1: `meas_sgfit_E661A4D41723262A_2023-09-27.txt` und Counter 2: `meas_sgfit_E661A4D41770802F_2023-09-27.txt`. Die beiden Kurven liegen sehr genau übereinander, da die Savitzky-Golay Filter die Unterschiede fast komplett weg-smoothen. Wobei man dazu sagen muss, dass die Unterschiede der Messungen von Counter 1 und 2 eh sehr klein sind und nur bei Rundsteuersignalen wirklich relevant sind.

Die Zeit auf der x-Achse ist immer die lokale Zeit.

#### Menüstruktur

- File->Read measurements - einlesen der Dateien die mit `meas_*` beginnen, ausser die mit lokaler Zeit.
- File->Read grid time - einlesen des Netzzeitoffsets `gridtime_*`, aber nicht mit lokaler Zeit.
- File->Read incidents - einlesen der Incidents, müssen zu der gewählten `meas_*` Datei passen.
- File->Remove incidents - entfernen der Incidents.
- File->Quit - verlassen des Programms.

Graphen können mit Rechtsklick gelöscht werden, entweder in dem man auf den graph clickt oder einen in der Legende auswählt.
Wenn man eine Netzzeitdatei läd kann es sein, dass man entlang der y-Achse rauszoomen muss um etwas zu sehen.

- View->Follow mode - geht in den follow mode mit atkueller Zeitspanne (siehe Zeile mit "Range:" unten links).
- View->Follow mode 5 mins - geht in den follow mode mit 5 Min Zeitspanne
- View->Follow mode 15 mins - geht in den follow mode mit 15 Min Zeitspanne
- View->Go to... - hier kann man einen Sprung an eine beliebige Stelle machen und die Zeitspanne in Minuten setzen.
- View->Jump to PoI - hier kann man einen Sprung an den ersten, letzten, vorherigen, nächsten Point of Interest machen.

Point of Interests sind aktuell nur Frequenzen von über 50.1 oder unter 49.9. Diese werden beim lesen der ersten `meas_*` Datei gesucht. Oder für den ersten Graph, wenn mehrere angezeigt werden, wenn man auf

- Analyze->Find PoIs in measurement #1

geht. PoIs werden auch gesucht wenn man den ersten Graph in der Liste der Graphen löscht.

- Help->Interactions - kurze Erklärung.
- Help->About Qt - Qt Standarddialog "About Qt".

### Incidents

Wenn der Pico W die Zeitstempel vom ATmega auswertet kann es passieren, dass Auffälligkeiten festgestellt werden. Dies führt dann zu einem Incident. Ob ein Incident vorliegt wird ab hier geprüft:
https://github.com/mcjurij/mfm/blob/bba71c24176cf02726d72ed47665e61a6f7a76e6/embedded/Pico_W/mfm/freq.c#L476

Es kann mehrere Incidents durch eine Messung geben. Der Hauptgrund für den Incident Mechanismus ist, dass ich in der Lage sein will zu erkennen, ob einer der beiden Counter
aufgrund von Alterungsprozessen, oder warum auch immer, mit der Zeit schlechtere Messungen liefert.

#### ERROR: measurement failed

https://github.com/mcjurij/mfm/blob/bba71c24176cf02726d72ed47665e61a6f7a76e6/embedded/Pico_W/mfm/freq.c#L481

Komplette Messung fehlgeschlagen.

#### ERROR: rise measurement failed

https://github.com/mcjurij/mfm/blob/bba71c24176cf02726d72ed47665e61a6f7a76e6/embedded/Pico_W/mfm/freq.c#L498

Messung der steigenden Flanken fehlgeschlagen.

#### ERROR: fall measurement failed
https://github.com/mcjurij/mfm/blob/bba71c24176cf02726d72ed47665e61a6f7a76e6/embedded/Pico_W/mfm/freq.c#L513

Messung der fallenden Flanken fehlgeschlagen.

#### NOTE: mains frequency of %.4f Hz too low

https://github.com/mcjurij/mfm/blob/bba71c24176cf02726d72ed47665e61a6f7a76e6/embedded/Pico_W/mfm/freq.c#L530

Netzfrequenz unter 49.9 Hz. Kann mit https://github.com/mcjurij/mfm/blob/f84038333c263206020d84a0b6d88ab9bdeef04e/embedded/Pico_W/mfm/conf.h#L15
gesetzt werden.

#### NOTE: mains frequency of %.4f Hz too high

https://github.com/mcjurij/mfm/blob/bba71c24176cf02726d72ed47665e61a6f7a76e6/embedded/Pico_W/mfm/freq.c#L544

Netzfrequenz über 50.1 Hz. Kann mit https://github.com/mcjurij/mfm/blob/f84038333c263206020d84a0b6d88ab9bdeef04e/embedded/Pico_W/mfm/conf.h#L16
gesetzt werden.

#### ERROR: rise vs fall deviation of %.4f%% too large

https://github.com/mcjurij/mfm/blob/bba71c24176cf02726d72ed47665e61a6f7a76e6/embedded/Pico_W/mfm/freq.c#L559

Abweichung der Messungen für fallende und steigende Flanken ist zu gross.

#### WARNING: rise vs fall deviation of %.4f%% large

https://github.com/mcjurij/mfm/blob/bba71c24176cf02726d72ed47665e61a6f7a76e6/embedded/Pico_W/mfm/freq.c#L573

Abweichung der Messungen für fallende und steigende Flanken ist gross.

#### WARNING: %.4f is too big of a jump

https://github.com/mcjurij/mfm/blob/bba71c24176cf02726d72ed47665e61a6f7a76e6/embedded/Pico_W/mfm/freq.c#L588

Sprung zwischen zwei aufeinanderfolgenden Messwerten zu gross.

#### ERROR: rise diff stddev of %.2f is too high

https://github.com/mcjurij/mfm/blob/bba71c24176cf02726d72ed47665e61a6f7a76e6/embedded/Pico_W/mfm/freq.c#L603

Die Standardabweichung der Messung mit steigenden Flanken ist zu gross.

#### ERROR: fall diff stddev of %.2f is too high

https://github.com/mcjurij/mfm/blob/bba71c24176cf02726d72ed47665e61a6f7a76e6/embedded/Pico_W/mfm/freq.c#L618

Die Standardabweichung der Messung mit fallenden Flanken ist zu gross.

#### ERROR: %d erratic diff(s)

https://github.com/mcjurij/mfm/blob/bba71c24176cf02726d72ed47665e61a6f7a76e6/embedded/Pico_W/mfm/freq.c#L634

Falsche Differenzen (im Code diffs genannt). Differenzen sind die Zeit zwischen zwei entweder steigenden oder fallenden Flanken.

#### WARNING: %d corrected diffs

https://github.com/mcjurij/mfm/blob/bba71c24176cf02726d72ed47665e61a6f7a76e6/embedded/Pico_W/mfm/freq.c#L650

Mehr als 4 korrigierte Differenzen. Differenzen müssen immer dann korrigiert werden, wenn auf ATmega Seite ein Zeitstempel bestimmt wurde der den letzten Überlauf des Zählerregisters noch nicht mitbekommen hatte. Da man immer sicher sagen kann, ob es sich um eine falsche Differenz oder eine wo ein Überlauf hinzuaddiert werden muss handelt, ist diese Korrektur sicher.

#### Anzeigen von Incidents im mfm_bwatcher

Zu einer Datei mit Messwerten zB `meas_data_<Pico ID>__<Date>.txt` kann man auch eine `incidents_<Pico ID>_<Date>.txt` dazu laden. Mit gleicher Pico ID und gleichem Datum. Das sieht dann zB so aus:

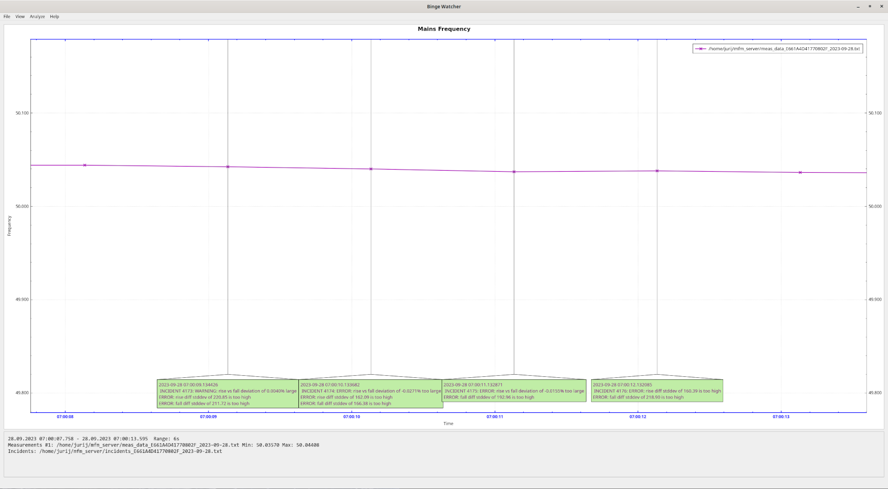
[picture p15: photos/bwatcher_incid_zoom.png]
Binge Watcher Incidents zoom


Um jedes Incident lesen zu können muss man entlang der x-Achse sehr stark reinzoomen, da sie sich überlappen. Daher ist die x-Achse selektiert und blau angezeigt. Zoomen mit Mausrad.
Die ist ein typischer Fall von Incidents die durch ein Rundsteuersignal ausgelöst werden. Das dürften so 95% aller Incidents sein.

Das Einblenden der Incidents verbraucht im mfm_bwatcher sehr viel CPU, wenn man zusätzlich in den Follow mode geht. Das benutzte Widget (QCustomPlot) ist für diese Anwendung nicht optimiert.

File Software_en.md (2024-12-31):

## Software

The software consists of 4 components. An embedded SW for the ATmega and Pico W respectively. A server that receives the data that comes in over WiFi. And a simple tool for graphical output of the data.

### Embedded

To transfer the cross-compiled SW to the MCUs, two completely different methods are used. The ATmega is programmed using an In System Programmer (ISP). The Pico W has a button. If it is held when the Pico W is turned on, the Pico W goes into a special boot sequence (which cannot be overwritten). This allows you to mount a “mass storage” via USB and copy a .uf2 file there. The Pico W recognizes this and then transfers it to its flash memory and start the newly flashed programm.

I can imagine that the Pico W can be used to program the ATmega. I didn't follow this due to lack of time. It would have the advantage that you don't need an extra ISP. However, because of the 3.3V I/O voltage of the Pico, you need a driver (also called a level shifter or logic converter) for implementation and I see a space problem. However, you probably wouldn't have it if you took a smaller representative of the ATmel series (i.e. ATtiny). The ATmega328p is clearly oversized for this application. ATmega/ATtiny also run with 3.3V, but I don't know whether that's enough for 10Mhz (I doubt it). And no more than 3.3 + 0.5 V can be applied to the inputs of the ATmega/ATtiny.

#### Atmel ATmega328p

The source code for the ATmega is here:
ATmega 328 src

There is only one file: `main.c`. Since the ATmega only determines the time stamps between the edges of the square wave signal and sends them to the Pico W via UART, not much happens here. The 1PPS signal is used to set the timestamp counter to 0.

In order for the Makefile to run, the avr-gcc toolchain and the avrdude tool must be installed to flash it. If the ISP fits the one in the Makefile and is connected, you can compile and flash in one go with `make program`.

#### Raspberry Pico W

The source code for the Pico W is here:
Pico W src

I don't use any OS. The programmer determines what should run on the two cores of the Pico Ws, core0 and core1. My choice is that the reading of the UART messages and processing of the timestamps coming from the ATmega is done on core1. Communication with the server on core0 (main() is started there).

The WiFi chip uses interrupts that are wired to Core0 and therefore the WiFi code can only run on core0.

In order to determine an exact time, the Pico W fetches the time from mfm_server when it starts. This returns the time of the host computer, which is inaccurate, but is not a problem as long as it is accurate enough to determine the correct second (the host computer usually gets its time via NTP. The method depends on the network latency). This is now compared with the 1PPS signal and this gives you a very precise time.
I don't use the Pico's clock (RTC). The Pico's standard crystal requires permanent time correction, no matter how you do it. The Pico has a counter that counts microseconds once started. To this value I add the microseconds since January 1, 1970 midnight (UTC). An interrupt routine that is linked to the 1PPS signal checks every second how many microseconds the counter needs to be corrected (+ microseconds since January 1, 1970 midnight (UTC)).
Since the time stamps of the ATmega are also synchronized with the 1PPS signal, the measurement time can be determined very precisely (at least in theory). As soon as a measurement has taken place, only the information in which second the measurement was taken comes from the Pico and the microsecond (start/end of the measurement) from the ATmega. The time of the measurement is halfway between the start and end of the measurement. It is important to note that the start or end of the measurement does not have to be on a second barrier and that a measurement can be longer (or shorter) than one second.

- `conf.h` - Configuration like MAINS_FREQ
- `freq.c` - Receives timestamp from ATmega and calculates frequency from it. Runs on core1.
- `main.c` - contains main() which starts on core0, starts core1. On core0, receives the data written from `freq.c` to `ringbuffer.c` and sends it to the mfm_server.
- `ntime.c` - Determine the exact time by combining time information from the Linux PC and 1PPS.
- `proto.c` - protocol definition.
- `tcp_client.c` - Communication with the mfm_server. The lwip call-back API is _very_ fiddly.
- `ringbuffer.c` - Saving measured values if network connection (briefly) not available.

First of all, set up the C SDK. https://www.raspberrypi.com/documentation/microcontrollers/c_sdk.html#sdk-setup
At https://www.raspberrypi.com/documentation/microcontrollers/c_sdk.html#quick-start-your-own-project you can find which Linux packages need to be installed.

Git clone, submodule init and set up environment variable.
```
git clone https://github.com/raspberrypi/pico-sdk.git

cd pico-sdk
git submodule update --init

export PICO_SDK_PATH=$HOME/<path to pico sdk>/pico-sdk/
```

Now go to the embedded/Pico_W/mfm directory to set the server IP which is the IP of the machine where the mfm_server runs.
```
cd embedded/Pico_W/mfm
```

To do this edit the line below in embedded/Pico_W/mfm/CMakeLists.txt.
``` 
 TCP_SERVER_IP=\"192.168.178.XXX\"
```

Change to Pico W directory (embedded/Pico_W) to do the cmake call.

```
cd ..

mkdir build
cd build

cmake -DPICO_BOARD=pico_w -DWIFI_SSID="<your SSID>" -DWIFI_PASSWORD="<your password>" ..
```

That should lead to the output below. I have blacked out my paths here.
cmake Ausgabe cmake

To build `make -j9`. The UF2 file used to flash is under `embedded/Pico_W/build/mfm/mfm_pico_w.uf2` (747 kb).

Next time you build you can just do a
```
cd build
make -j9
```
and leave out the cmake call.

### On the Linux PC

The mfm_server runs on a Linux PC and accepts the data that comes from the Pico Ws via WiFi, processes it and writes it into files. These can be read by a GUI, the “Binge Watcher” or mfm_bwatcher.

The output made with printf() is transferred via USB. To do this, enter `minicom -C minicom.log -b 115200 -o -D /dev/ttyACM0` on the Linux PC after the Pico W has started. The transfer of output via USB sometimes hangs for me (after several hours or days). But the Pico W still runs.

After starting the Pico W, an attempt is made to connect to the WiFi (the SSID and password are passed on when calling cmake, as shown above), and if successful, time synchronization with the Linux PC is carried out. After that time stamps from the ATmega are processed. If nothing "unusual" happens this will be printed about every 4 seconds:
```
Interrupt handler count msg: XXX
```
Where XXX is the number of timestamps already processed.

#### mfm_server

The mfm_server should build directly with a `make`.
The server starts one thread per connection, i.e. per Counter. The two threads then pass the measured values to a collector thread, which writes out the data for each counter and also combines them.

The mfm_server is not (yet) a real server; it lacks so-called daemonizing, which includes decoupling from the terminal. Currently there is also no way to shut down the server cleanly with a control program.

- `conn_slots.c` - each Pico W gets its own connection slot, uses the Pico ID to recognize that the same Pico W has connected.
- `file_mgr.c` - File management and rotation.
- `process_data.c` - Data evaluation.
- `proto.c` - Protocol definition, exact copy of the file in the embedded/Pico_W/mfm directory.
- `server.c`- Contains main(), accepts network connections and starts one thread per Pico W.

The Picos have a unique ID, which can be queried with https://github.com/mcjurij/mfm/blob/85a41c4bb33529b7771d14aba3f1979061e204ab/embedded/Pico_W/mfm/main.c#L51. In the mfm_server it is used in particular to determine the file names for the Counter-related files. After a Pico W has established a connection to the mfm_server, it first sends its ID.

In order for the Pico Ws to contact the mfm_server, you probably have to open port 4200 in a firewall, depending on your Linux distro.
On my Fedora this is done using
```
firewall-cmd --permanent --add-port=4200/tcp

firewall-cmd --reload
```
as root.

##### Output data files

In addition to mfm_server's own log file `log.txt`, various files are written and continuously appended. If a file comes from a specific Counter, the file name contains the Pico ID. In any case the current date. With an example day, I'll take 2023-09-25, this quickly becomes clear. The first column of all files there is always has a time, either in us-Epoch or Epoch. The us-Epoch are microseconds since January 1, 1970 midnight (UTC, a 16-digit number). The Epoch are seconds since January 1, 1970 midnight (UTC). My Pico Ws have the IDs Counter 1: E661A4D41723262A, Counter 2: E661A4D41770802F.

| File name | Contents |
| --- | --- |
|`meas_data_E661A4D41723262A_2023-09-25.txt`|Measurements from Counter 1 with us-Epoch time|
|`meas_data_E661A4D41770802F_2023-09-25.txt`|Measurements from Counter 2 with us-Epoch time|
|`meas_data_local_E661A4D41723262A_2023-09-25.txt`|Measurements form Counter 1 with local time|
|`meas_data_local_E661A4D41770802F_2023-09-25.txt`|Measurements form Counter 2 with local time|
|`meas_sgfit_E661A4D41723262A_2023-09-25.txt`|Measurements form Counter 1 with us-Epoch time, with interpolation & Savitzky-Golay filter|
|`meas_sgfit_E661A4D41770802F_2023-09-25.txt`|Measurements form Counter 2 with us-Epoch time, with interpolation & Savitzky-Golay filter|
|`meas_sgfit_local_E661A4D41723262A_2023-09-25.txt`|Measurements form Counter 1 with lokaler time, with interpolation & Savitzky-Golay filter|
|`meas_sgfit_local_E661A4D41770802F_2023-09-25.txt`|Measurements form Counter 1 with lokaler time, with interpolation & Savitzky-Golay filter|
|`meas_merge_2023-09-25.txt`|merged measurements form Counter 1 & 2 with us-Epoch time, with interpolation|
|`meas_merge_sgfit_2023-09-25.txt`|merged measurements form Counter 1 & 2 with us-Epoch time, with interpolation & Savitzky-Golay filter|
|`gridtime_2023-09-25.txt`|Grid time with Epoch time|
|`gridtime_local_2023-09-25.txt`|Grid time with local time|
|`incidents_E661A4D41723262A_2023-09-25.txt`|Incidents form Counter 1|
|`incidents_E661A4D41770802F_2023-09-25.txt`|Incidents form Counter 2|

Interpolation is simply interpolating linearly between two measured values in such a way that one value per second is obtained . The Savitzky-Golay filter (in this form) can only work with equidistant values. With `meas_merge_*` the average is taken from the two interpolations of Counters 1 and 2. With `meas_merge_sgfit_*`, Counters 1 & 2 are first interpolated, then the Savitzky-Golay filter is applied and then the average of these two values is taken.

The grid time is calculated from the measured values written to `meas_merge_sgfit_*`. In `gridtime_2023-09-25.txt` the Epoch time is in the first column. These are the seconds since January 1, 1970 midnight (UTC). In the second column is the grid time offset.

You can see the effect the Savitzky-Golay filter on the measured values in the mfm_bwatcher, for example when loading `meas_data_E661A4D41723262A_2023-09-25.txt` _and_ `meas_sgfit_E661A4D41723262A_2023-09-25.txt`. Implementation see 
https://github.com/mcjurij/mfm/blob/0261355ed0bb614fb97571ce3041f7e02aebb63d/mfm_server/process_data.c#L542

There are various things in the mfm_server log file `log.txt`: messages about time synchronization, messages about file rotation, messages about implausibly long intervals between 2 measurements, messages about received incidents.

I'll write something about incidents below.

##### Start with grid time

When starting the mfm_server, the "official" grid time from e.g. https://www.swissgrid.ch/de/home/operation/grid-data/current-data.html#wide-area-monitoring (please scroll down) can be used as a command line argument.
The value of "Aktuelle Netzzeitabweichung:" ("current grid time deviation:") is the difference between grid time minus the current time.

E.g. 
```
./mfm_server 15.23
```
starts the mfm_server so that instead of 0, 15.23 seconds is used as the grid time offset at the time of start. This is not perfectly accurate, as there is a pause between the start of the program and the start of our own grid time calculation, but it is sufficient.

#### mfm_bwatcher

A simple tool for graphical output of data, similar to a function plotter, but with a few special features for this application. Qt 6 must be installed. I'm currently using Qt 6.4.3 and Qt Creator.
To configure the project go to File->Open File or Project, then load `mfm_bwatcher.pro`, then under "Configure Project" just select "Desktop ..." and click on the "Configure Project" button. Then click on the green triangle “Run” at the bottom left. This will build and start the mfm_bwatcher GUI.

The mfm_bwatcher only understands the files that have a us-Epoch or Epoch time (such as `meas_data_E661A4D41770802F_2023-09-25.txt`), not those with local time (such as `meas_data_local_E661A4D41770802F_2023-09-25.txt`). The ones with local time are intended for other plotters such as gnuplot. The file for the grid time (e.g. `gridtime_2023-09-25.txt` see above) may only have the Epoch time in the first column.

Binge Watcher Follow Mode

This screenshot shows the data from Counter 1: `meas_data_E661A4D41723262A_2023-09-27.txt` and `meas_sgfit_E661A4D41723262A_2023-09-27.txt`. You can see the effect of the Savitzky-Golay filter.
In "Follow mode" the files from the mfm_server are always read again at the end and the graph is updated every second. The follow mode can be recognized by the box with the value and the arrow pointing to the right y-axis (called AxisTag in the source code).

Binge Watcher Follow Mode

This screenshot shows the data of Counter 1: `meas_sgfit_E661A4D41723262A_2023-09-27.txt` and Counter 2: `meas_sgfit_E661A4D41770802F_2023-09-27.txt`. The two curves lie very precisely on top of each other, as the Savitzky-Golay filters almost completely smooth out the differences. It has to be said that the differences between the measurements from Counters 1 and 2 are very small anyway and are only really relevant for ripple control signals.

The time on the x-axis is always local time.

#### Menu structure

- File->Read measurements - read files that start with `meas_*` except those with local time.
- File->Read grid time - read the grid time offset `gridtime_*`, but not with local time.
- File->Read incidents - read the incidents, must match the selected `meas_*` file.
- File->Remove incidents - remove the incidents.
- File->Quit - exit the program.

Graphs can be deleted with a right click, after clicking on the graph or picking one in the legend.

After loading grid time file you may have to zoom out along the y-Axis to see anything.

- View->Follow mode - switches to follow mode with the current time range (see line with "Range:" at the bottom left).
- View->Follow mode 5 mins - switches to follow mode with a 5 min time range.
- View->Follow mode 15 mins - switches to follow mode with a 15 min time range.
- View->Go to... - here you can jump to any point in time and set the time range in minutes.
- View->Jump to PoI - here you can jump to the first, last, previous, next point of interest (PoI).

Points of interest are found currently only when the mains frequency goes above 50.1 or below 49.9 Hz. They are searched when reading the first `meas_*` file. Or for the first graph if several are displayed and you select

- Analyze->Find PoIs in measurement #1

They are also searched when you remove the first graph in the list of graphs.

- Help->Interactions - short explanation of mouse interactions.
- Help->About Qt - Qt's standard dialog "About Qt".

### Incidents

When the Pico W evaluates the time stamps from the ATmega, it can happen that abnormalities are detected. This then leads to an incident. Whether there is an incident is checked in the source code from here on:
https://github.com/mcjurij/mfm/blob/bba71c24176cf02726d72ed47665e61a6f7a76e6/embedded/Pico_W/mfm/freq.c#L476

There can be multiple incidents caused by one measurement. The main reason for the incident mechanism is that I want to be able to detect if a Counter delivers poorer measurements over time, due to aging processes, or for whatever reason.

#### ERROR: measurement failed

https://github.com/mcjurij/mfm/blob/bba71c24176cf02726d72ed47665e61a6f7a76e6/embedded/Pico_W/mfm/freq.c#L481

#### ERROR: rise measurement failed

https://github.com/mcjurij/mfm/blob/bba71c24176cf02726d72ed47665e61a6f7a76e6/embedded/Pico_W/mfm/freq.c#L498

#### ERROR: fall measurement failed

https://github.com/mcjurij/mfm/blob/bba71c24176cf02726d72ed47665e61a6f7a76e6/embedded/Pico_W/mfm/freq.c#L513

#### NOTE: mains frequency of %.4f Hz too low

https://github.com/mcjurij/mfm/blob/bba71c24176cf02726d72ed47665e61a6f7a76e6/embedded/Pico_W/mfm/freq.c#L530

Mains frequency below 49.9 Hz. Can be set here https://github.com/mcjurij/mfm/blob/f84038333c263206020d84a0b6d88ab9bdeef04e/embedded/Pico_W/mfm/conf.h#L15 .

#### NOTE: mains frequency of %.4f Hz too high

https://github.com/mcjurij/mfm/blob/bba71c24176cf02726d72ed47665e61a6f7a76e6/embedded/Pico_W/mfm/freq.c#L544

Mains frequency above 50.1 Hz. Can be set here https://github.com/mcjurij/mfm/blob/f84038333c263206020d84a0b6d88ab9bdeef04e/embedded/Pico_W/mfm/conf.h#L16 .

#### ERROR: rise vs fall deviation of %.4f%% too large

https://github.com/mcjurij/mfm/blob/bba71c24176cf02726d72ed47665e61a6f7a76e6/embedded/Pico_W/mfm/freq.c#L559

Deviation of the measurements for falling and rising edges is too large.

#### WARNING: rise vs fall deviation of %.4f%% large

https://github.com/mcjurij/mfm/blob/bba71c24176cf02726d72ed47665e61a6f7a76e6/embedded/Pico_W/mfm/freq.c#L573

Deviation of the measurements for falling and rising edges is large.

#### WARNING: %.4f is too big of a jump

https://github.com/mcjurij/mfm/blob/bba71c24176cf02726d72ed47665e61a6f7a76e6/embedded/Pico_W/mfm/freq.c#L588

Jump between two consecutive measurements is too large.

#### ERROR: rise diff stddev of %.2f is too high

https://github.com/mcjurij/mfm/blob/bba71c24176cf02726d72ed47665e61a6f7a76e6/embedded/Pico_W/mfm/freq.c#L603

The standard deviation of the measurement with rising edges is too large.

#### ERROR: fall diff stddev of %.2f is too high

https://github.com/mcjurij/mfm/blob/bba71c24176cf02726d72ed47665e61a6f7a76e6/embedded/Pico_W/mfm/freq.c#L618

The standard deviation of the measurement with falling edges is too large.

#### ERROR: %d erratic diff(s)

https://github.com/mcjurij/mfm/blob/bba71c24176cf02726d72ed47665e61a6f7a76e6/embedded/Pico_W/mfm/freq.c#L634

Erratic differences (called diffs in the code). Diffs are the time between either two rising or two falling edges.

#### WARNING: %d corrected diffs

https://github.com/mcjurij/mfm/blob/bba71c24176cf02726d72ed47665e61a6f7a76e6/embedded/Pico_W/mfm/freq.c#L650

More than 4 corrected differences. Differences must always be corrected if a time stamp was determined on the ATmega side that needs the last overflow of the counter register added to it. This is a save operation since we can clearly distinguish an erratic diff from one that needs one counter overflow added to it.

#### Display incidents in the mfm_bwatcher

For a file with measurement values, for example `meas_data_<Pico ID>__<Date>.txt`, you can also load the matching `incidents_<Pico ID>_<Date>.txt`. With the same Pico ID and the same date. It looks like this:
Binge Watcher Incidents zoom

In order to be able read each incident you have to zoom in a lot along the x-axis until they no longer overlap. Therefore the x-axis is selected and displayed in blue. Zoom with mouse wheel.
This is a typical case of incidents that are triggered by a ripple control signal. That's probably 95% of all incidents.

Showing incidents consumes a lot of CPU in mfm_bwatcher, once you go into follow mode. The widget used (QCustomPlot) is not optimized for this kind of application.

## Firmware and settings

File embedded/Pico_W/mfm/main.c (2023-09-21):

#include <stdio.h>
#include <stdint.h>
#include <string.h>
#include "pico/stdlib.h"
#include "pico/multicore.h"
#include "pico/mutex.h"
#include "pico/unique_id.h"

#include "conf.h"

#include "pico/cyw43_arch.h"


#include "test_tcp_client.h"
#include "tcp_client.h"

#include "freq.h"
#include "ntime.h"
#include "proto.h"
#include "ringbuffer.h"

#define DEBUG_printf printf
// #define TEST_DA

void setup_gpios();

#define MAX_SAMPLES 500
#define MAX_INCIDENTS 25

static ringbuffer_t samples, incidents;
void core1_entry();

uint8_t clock_state_comp;

int main()
{
    stdio_init_all();
    sleep_ms( 1000 );

    build_protos();
    
    ringbuffer_init( &samples, MAX_SAMPLES, sizeof(sample_t));
    ringbuffer_init( &incidents, MAX_INCIDENTS, sizeof(incident_t));
    
    /*
      pico_unique_board_id_t boardID;
      pico_get_unique_board_id(&boardID);
    */

    char idstr[ 2 * PICO_UNIQUE_BOARD_ID_SIZE_BYTES + 1 ];
    pico_get_unique_board_id_string( idstr, 2 * PICO_UNIQUE_BOARD_ID_SIZE_BYTES + 1);
    
    printf( "Pico board id: %s\n", idstr);

    pico_unique_board_id_t id;
    pico_get_unique_board_id( &id );
    unsigned int rand_seed = 0;
    for( int i = 0; i<8; i++)
        rand_seed += id.id[i];
    srand( rand_seed );

    printf( "rand seed = %u\n", rand_seed);
    
    printf("configuring pins...\n");
    setup_gpios();

#if defined(TEST_DA)
    multicore_launch_core1( core1_entry );
#endif
    
    if (cyw43_arch_init())
    {
        DEBUG_printf("failed to initialise WiFi\n");
        return 1;
    }
    
    cyw43_arch_enable_sta_mode();
    
    if( cyw43_wifi_pm(&cyw43_state, cyw43_pm_value(CYW43_NO_POWERSAVE_MODE , 20, 1, 1, 1)) == 0 )
        printf( "PM mode = no powersave for CYW43\n" );
    
    int a = 10;
    bool con = false;
    do {
        printf("Connecting to WiFi '%s' ...\n", WIFI_SSID);
        if (cyw43_arch_wifi_connect_timeout_ms( WIFI_SSID, WIFI_PASSWORD, CYW43_AUTH_WPA2_AES_PSK, 30000))
        {
            sleep_ms( 3000 );
        }
        else
        {
            printf("Connected to WiFi.\n");
            con = true;
            break;
        }
    } while( --a > 0 );
    
    if( !con )
    {
        printf("Failed to connect. Exiting.\n");
        return 1;
    }

    TCP_CLIENT_T *state = client_open();

    if( state )
    {
        if( !client_do_ping( state ) )
        {
            printf( "ping failed - exiting\n" );
            return 1;
        }
        
        if( !client_do_idnt( state, idstr) )
        {
            printf( "sending id string failed - exiting\n" );
            return 1;
        }

        setup_clock();
        
        client_initial_adjust_time( state );
        
        multicore_launch_core1(core1_entry);  // core1 does communication with the ATmega

        int c_loops = 0;
        clock_state_comp = CLOCK_STATE_INVALID;
            
        while( true )
        {
            int rand_wait = (int)((1. + 20.) * rand() / ( RAND_MAX + 1. ) );
            sleep_ms( 1000 + rand_wait );   // wait roughly 1s, random part is to avoid wifi collision with other picow.
                                            // not sure if this really is much of a gain.
            
            c_loops++;
            if( c_loops == 4 )
            {
                c_loops = 0;
                int64_t server_time_us, pico_time_us = ntime_now();
                client_do_clcp( state, pico_time_us, &server_time_us);
                int64_t rr_time_us = ntime_now() - pico_time_us;

                if( rr_time_us < 20000 )  // 20ms
                {
                    if( llabs( pico_time_us - server_time_us ) >= 200000 )  // 200ms
                    {
                        incident_t incident;
                        incident.time = pico_time_us;
                        incident.fall_size = incident.rise_size = 0;
                        
                        char buf[80];
                        snprintf( buf, 80, "SYSTEM ERROR: Clock broken, Pico minus server time %lld us (RTT %lld)", pico_time_us - server_time_us, rr_time_us);
                        strcpy( incident.reason, buf);
                        
                        if( !producer_put( &incidents, &incident) )
                            printf( "incident buffer full!\n" );

                        clock_state_comp = CLOCK_STATE_COMP_BROKEN;
                        printf( "Clock broken, Pico minus server time %lld us (RTT %lld)\n", pico_time_us - server_time_us, rr_time_us);
                    }
                    else
                        clock_state_comp = CLOCK_STATE_COMP_OK;
                }
                else
                {
                    incident_t incident;
                    incident.time = pico_time_us;
                    incident.fall_size = incident.rise_size = 0;
                    
                    char buf[130];
                    snprintf( buf, 130, "WARNING: Clock check took too long, %lld round trip time (Pico minus server time %lld us)", rr_time_us, pico_time_us - server_time_us);
                    strcpy( incident.reason, buf);
                    
                    if( !producer_put( &incidents, &incident) )
                        printf( "incident buffer full!\n" );

                    clock_state_comp = CLOCK_STATE_COMP_TOO_LONG;
                    printf( "Clock check took too long, %lld round trip time (Pico minus server time %lld us)\n", rr_time_us, pico_time_us - server_time_us);
                }
                
                printf( "Interrupt handler count msg: %u\n", get_intr_cnt_msg());
            }
            
            // printf("--------------------------------------------\n");
            uint32_t s, d;
            double t;
            
            int c_to_send;
            consumer_get_tail( &samples, &c_to_send);
            if( c_to_send > 0 )
            {
                // printf( "Samples to send: %d\n", c_to_send);
                
                s = time_us_32();
                while( !client_do_meas( state, &samples, c_to_send) )
                {
                    // now, we have a problem. Client can't send data.
                    printf( "Urgh... client_do_meas() failed\n" );

                    client_try_reconnect( state, idstr);

                    consumer_get_tail( &samples, &c_to_send);
                }
                d = time_us_32() - s;
                t = ((double)d) / 1000000.;
                if( t > 0.01 )
                    printf( "All client_do_meas() took %.3fs\n", t);
                
                consumer_move_tail( &samples );
                c_to_send = 0;
            }
            else
            {
                printf( "No samples to send, interrupt handler count msg: %u\n", get_intr_cnt_msg());
                adjust_clock();
            }

            
            consumer_get_tail( &incidents, &c_to_send);
            if( c_to_send > 0 )
            {
                // printf( "Incidents to send: %d\n", c_to_send);
                
                s = time_us_32();
                while( !client_do_incd( state, &incidents, c_to_send) )
                {
                    // now, we have a problem. Client can't send data.
                    printf( "Urgh... client_do_incd() failed\n" );
                    
                    client_try_reconnect( state, idstr);

                    consumer_get_tail( &incidents, &c_to_send);
                }
                d = time_us_32() - s;
                t = ((double)d) / 1000000.;
                if( t > 0.01 )
                    printf( "All client_do_incd() took %.3fs\n", t);
                
                consumer_move_tail( &incidents );
                c_to_send = 0;
            }
            else
            {
                // adjust_clock();
            }
        }
    }

    
    // cyw43_arch_deinit();
    
    return 0;
}


void setup_gpios()
{
    init_gpios_freq();
}


void core1_entry()
{
    setup_freq();
    
    if( !discard_startup_garbage_from_atmega() )
    {
        printf( "Collecting data from ATmega on core1 failed!\n" );
        return;
    }
    
    printf("Collect data from ATmega on core1\n");
    uint32_t sample_number = 0;
    while( true )
    {
        meas_ctxt_t meas_ctxt;
        meas_ctxt.cnt_meas_rise = 0;
        meas_ctxt.cnt_meas_fall = 0;
        bool ok = collect_data_from_atmega( &meas_ctxt );

        incident_t incident;
        if( !ok )
        {
            incident.time = ntime_now();
            strcpy( incident.reason, "SYSTEM ERROR: No, no proper or not enough data from ATmega");
            incident.fall_size = incident.rise_size = 0;
            
            if( !producer_put( &incidents, &incident) )
                printf( "incident buffer full!\n" );
            
            continue;
        }
        
        sample_t sample;
        analyze_atmega_data( &meas_ctxt, &sample, &incident);
        sample.number = ++sample_number;
        
        if( sample.time == 0 || sample.freq < 0. )
            printf( "error during analyze data from ATmega\n" );
        else
        {
            sample.clock_state_1pps = get_clock_state_1pps();
            sample.clock_state_comp = clock_state_comp;
            
            // put sample in the ring buffer
            if( !producer_put( &samples, &sample) )
                printf( "sample buffer full!\n" );
        }

        if( incident.time != 0 )
        {
            // put incident in the ring buffer
            if( !producer_put( &incidents, &incident) )
                printf( "incident buffer full!\n" );
        }
    }
}

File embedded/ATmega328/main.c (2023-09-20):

#include <string.h>
#include <stdio.h>
#include <stdlib.h>
#include <stdbool.h>

#include <avr/io.h>
#include <util/delay.h>

#include <avr/interrupt.h>

// turn transmit hex on for debugging
// #define TRANSMIT_HEX

// https://www.mikrocontroller.net/articles/High-Speed_capture_mit_ATmega_Timer

#define LED PD7

static void uart_puts( const char * s );
static char uart_getc(void);

static void do_measure();

int main()
{
    // Set port D
    DDRD = _BV(LED);

    // configure UART
    // F_CPU has to be set for this to work
    // see https://www.nongnu.org/avr-libc/user-manual/group__util__setbaud.html
//#define BAUD 115200
// 156250 works for 10 Mhz clock
#define BAUD 156250
    
#include <util/setbaud.h>
    UBRR0H = UBRRH_VALUE;
    UBRR0L = UBRRL_VALUE;
#if USE_2X
    UCSR0A |= (1 << U2X0);
#else
    UCSR0A &= ~(1 << U2X0);
#endif
    
    UCSR0C = 3<<UCSZ00;  // 8N1
    
    // UCSR0C |= 1 << USBS0; // 2 stop bits
    
	// UCSR0B = (1<<TXEN0); // enable transmitter
    UCSR0B |= (1 << RXEN0) | (1 << TXEN0); // enable transmitter & receiver 
    
    
    DDRB &= ~(1 << DDB1);         // Clear the PB1 pin
    // PB0 (PCINT0 pin) is now an input
    PORTB = 0;
    // PORTB |= (1 << PORTB1);        // turn On the Pull-up

    /*
    PCICR |= (1 << PCIE0);     // set PCIE0 to enable PCMSK0 scan
    PCMSK0 |= (1 << PCINT1);   // set PCINT1 to trigger an interrupt on state change

    sei();                     // turn on interrupts
    */

    do_measure();
}



/*
ISR (PCINT0_vect)
{
    if( (PINB & (1 << PINB1))  )
    {
        // LOW to HIGH pin change
        uart_puts("- L->H");
        PORTD ^= _BV(LED);
    }
    else
    {
        // HIGH to LOW pin change
    }
}
*/

// +-----------------------------------------------------------------------+ //
static char uart_getc(void)
{
    // wait for data
    while(!(UCSR0A & (1 << RXC0)))
        ;

    return UDR0;
}


static void uart_putc( char c )
{
    while( !( UCSR0A & (1<<UDRE0)) )  // wait for empty transmit buffer
        ;
    UDR0 = c;
}


static void uart_puts( const char * s )
{
    for( int i = 0; s[i] != 0; i++)
        uart_putc( s[i] );
}


static void uart_print( const char *s )
{
    uart_puts( s );
}


static void uart_println( const char *s )
{
    uart_puts( s );
    uart_putc( '\n' );
}



#define OVL_CNT 65536

static uint8_t ovl;  // counts overflows
static uint16_t sec_barrier_cnt;  // remember counter value from seconds barrier
// reset whenever 1PPS has a rising edge
// F_CPU must be 10Mhz, 1PPS connected to PINB1
// floor(10000000/ovl_val) = 152
#define RESET_OVL {if( ovl >= 150 && (PINB & (1 << PINB1)) ) { sec_barrier_cnt = TCNT1; ovl = 0;}}

static void uart_send_meas_putc( uint8_t c )
{
    while( !( UCSR0A & (1<<UDRE0)) )
        RESET_OVL;               // ; to make emacs happy
    UDR0 = c;
}

#if defined(TRANSMIT_HEX)
static const char hexvals[16] = {
    '0', '1', '2', '3',
    '4', '5', '6', '7',
    '8', '9', 'A', 'B',
    'C', 'D', 'E', 'F'
};

static void uart_send_meas_printbhex( uint8_t b )
{
    uart_send_meas_putc( hexvals[ b >> 4 ] );
    RESET_OVL;
    uart_send_meas_putc( hexvals[ b & 0xf ] );
    RESET_OVL;
}

static void uart_send_meas_printwhex( uint16_t w )
{
    uart_send_meas_printbhex( w >> 8 );
    RESET_OVL;
    uart_send_meas_printbhex( w & 0xff );
    RESET_OVL;
}

static void uart_send_meas_printtshex( uint32_t ts )  
{
    uart_send_meas_printbhex( (ts >> 24) & 0xff );
    RESET_OVL;
    uart_send_meas_printbhex( (ts >> 16) & 0xff );
    RESET_OVL;
    uart_send_meas_printbhex( (ts >> 8) & 0xff );
    RESET_OVL;
    uart_send_meas_printbhex( ts & 0xff );
    RESET_OVL;
}

#else

static void uart_send_meas_printts( uint32_t ts )  
{
    uint8_t *c = (uint8_t *)&ts;
    uint8_t chk = c[0] + c[1] + c[2] + c[3]; // overflow intentional
    RESET_OVL;
    uart_send_meas_putc( c[0] );
    uart_send_meas_putc( c[1] );
    uart_send_meas_putc( c[2] );
    uart_send_meas_putc( c[3] );
    uart_send_meas_putc( chk );
}
#endif

// counter for led blink
static uint8_t led_c = 0;

// sends 32 bit timestamp to PicoW
// 1 byte signature
// 4 byte timestamp (binary)
// 1 byte checksum (binary)
// 1 byte return char
// if TRANSMIT_HEX is on it is 1 + 8 + 1, no checksum in hex mode
static void uart_send_meas( char sig, uint32_t ts)
{
    uart_send_meas_putc( sig );    // signature '/' => rising edge, '\' => falling edge
    
#if defined(TRANSMIT_HEX)
    uart_send_meas_printtshex( ts );
#else
    uart_send_meas_printts( ts );
#endif
    
    uart_send_meas_putc( '\n' );

    if( led_c == 50 )
    {
        PORTD ^= _BV(LED);
        led_c = 0;
    }
    else
        led_c++;
    RESET_OVL;
}


static void loop()
{
    bool rise = true;
    TCCR1B = 0x41;      // rising edge, no prescaler
    TIFR1 = (1<<ICF1);      // clear ICF flag
    uint16_t cap = 0;
    uint8_t cap_ovl;
    int32_t timestamp;
    
    while( true )
    {
        if(  ovl >= 150 && (PINB & (1 << PINB1)))  // 1PPS low->high transition?
        {
            ovl = 0;
            sec_barrier_cnt = TCNT1;
        }
        
        register uint8_t tifr = TIFR1;
        if( (tifr & _BV(ICF1)) )  // check for capture
        {
            cap = ICR1;                           // take value of capture register
            TIFR1 = (1<<ICF1);                    // clear capture
            
            if( ovl > 0 )
            {
                cap_ovl = ovl;
                timestamp = (int32_t)cap + cap_ovl * OVL_CNT - (int32_t)sec_barrier_cnt;
            }
            else if( cap < sec_barrier_cnt )  // timestamps must never be negative
            {
                cap_ovl = ovl = 1;
                timestamp = (int32_t)cap + OVL_CNT - (int32_t)sec_barrier_cnt;
            }
            else
            {
                cap_ovl = 0;
                timestamp = (int32_t)cap - (int32_t)sec_barrier_cnt;
            }
            
            if( rise )
                uart_send_meas( '/', timestamp);    // send rising timestamp to PicoW
            else
                uart_send_meas( '\\', timestamp);   // send falling timestamp to PicoW
            
            rise = !rise;
            if( rise )
                TCCR1B = 0x41;      // rising edge, no prescaler
            else
                TCCR1B = 0x01;      // falling edge, no prescaler
        }
        
        if( (tifr & _BV(OCF1A)) )        // check for overflow
        {
            TIFR1 = _BV(OCF1A);
            
            ovl++;
        }
    }
}
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

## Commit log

2023-09-21 init Pico W
2023-09-27 KiCad schematics
    [counter_distributor.kicad_sch, counter_mcu.kicad_sch, counter_mcu_v2.kicad_sch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]
2023-09-27 correct KiCad schematic
2023-09-29 Notes for people not in the 50 Hz / 230 V domain
2023-10-12 mention transformer output current
    [counter_ps.kicad_sch]
2023-10-30 transformer output voltage mentioned
    [counter_ps.kicad_sch]
2023-12-20 2nd 22u not needed
    [counter_ps.kicad_sch]
2023-12-20 mention transformer primary voltage
2024-04-23 reduce printfs
2024-12-31 do not reset y axis
